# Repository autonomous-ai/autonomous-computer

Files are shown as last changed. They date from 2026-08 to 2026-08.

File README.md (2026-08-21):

# Time to build your own Personal AI Computer

https://github.com/user-attachments/assets/36f7aa02-42ac-4b35-b757-a5dd3b43ef1a

## Prefer a finished machine?

Building from this guide is the full DIY path. If you'd rather skip sourcing, CNC, and assembly, we have it covered — [order a Personal AI Computer](https://www.autonomous.ai/computer/buy).

## The future of AI is local

AI in 2026 looks like computing in 1975: the intelligence lives in a few mainframes, owned by a few companies, and you rent it by the token. Everyone knows how that movie ends. The machine moves onto the desk — and the people who own their machines build everything that comes next.

The Personal AI Computer is that machine. The models are good, the GPUs are affordable, and homes and businesses are reaching the same answer: bring it in-house. Three reasons:

1. **No one can switch you off.** In June 2026 the US government took Fable 5 offline for most of a month and gated GPT-5.6 behind an approved-partner list. Weights on your own disk can't be revoked.
2. **Your business is their training data.** Every prompt you send OpenAI or Anthropic carries your product, your process, your edge. They will turn your secret sauce into their product.
3. **Inference becomes free.** Open weights on a cloud API already cut the bill 20–30×. On your own machine there is no bill at all. No API, no meter.

## The end-to-end open-source local AI stack

Open software lets you run and shape your AI; open hardware lets you build, repair, and improve the machine it runs on. With both in your hands — the code, the CAD, the BOM, the BIOS settings — you can build the whole thing end to end. So we open-source both:

- **Open Source Hardware — this repo.** Your Personal AI Computer in five builds, below: every part, every bracket, every BIOS setting, every assembly photo.
- **Open Source Software — your choice.** The easiest way is [Grid](https://github.com/autonomous-ai/autonomous-grid), the open orchestrator for local AI — but any local AI engine works: vLLM, Ollama, llama.cpp.

## 2× NVIDIA RTX 5090

The entry-level build, for personal use. Enough for Llama, Qwen, and DeepSeek with quantization — run OpenClaw, Hermes Agent, or your own LangChain stack locally.

- **2× NVIDIA RTX 5090** — 64 GB VRAM · 3,584 GB/s · 419 FP32 TFLOPS
- **Intel Xeon W5** (ASUS W790 ACE) · 96 GB RAM · 1 TB NVMe
- **PCIe Gen 5 ×16** per GPU · 10 GbE + 2.5 GbE
- **1,550 W draw** · 1,600 W PSU
- **12.5″ × 12.5″ × 16″** · 33 lb

**[Build the 2× 5090 →](2x-5090/README.md)**

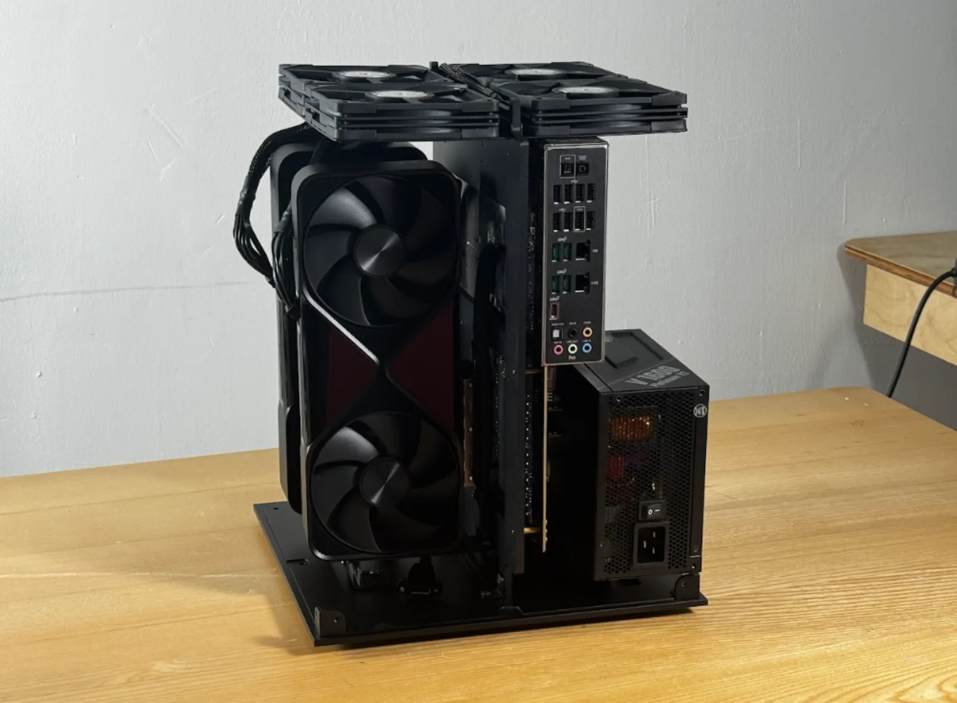
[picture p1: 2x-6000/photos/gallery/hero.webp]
The 2× 5090 build — two RTX 5090s on the open frame


<table>
<tr>
<td width="50%">Seating the PCIe riser</td>
<td width="50%">Mounting the PCIe 5.0 risers</td>
</tr>
<tr>
<td width="50%">The fan tray</td>
<td width="50%">Closing the side panel</td>
</tr>
</table>

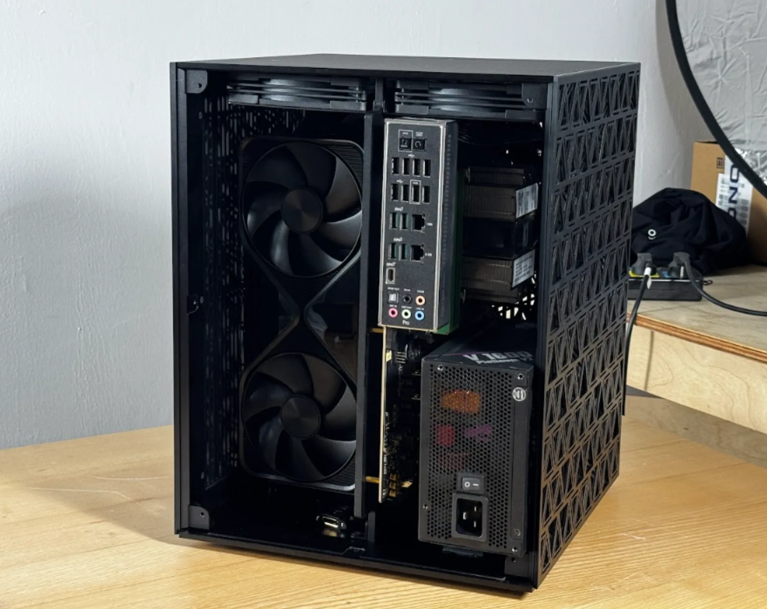
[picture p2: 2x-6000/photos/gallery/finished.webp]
The finished 2× 5090


## 2× NVIDIA RTX PRO 6000

The same desk-sized box, three times the VRAM. 192 GB of ECC memory on two cards — run the big open models as released instead of quantizing them down to fit.

- **2× NVIDIA RTX PRO 6000 Blackwell** — 192 GB GDDR7 ECC · 3,584 GB/s (96 GB per card)
- **Intel Xeon W5** (ASUS W790 ACE) · 96 GB RAM · 1 TB NVMe
- **PCIe Gen 5 ×16** per GPU · 10 GbE + 2.5 GbE
- **1,600 W draw** · 1,600 W PSU
- **12.5″ × 12.5″ × 16″** · 33 lb

**[Build the 2× 6000 →](2x-6000/README.md)**

<a href="2x-6000/README.md">The 2× 6000 build — two RTX PRO 6000s on the open frame with the fan tray on top</a>

<table>
<tr>
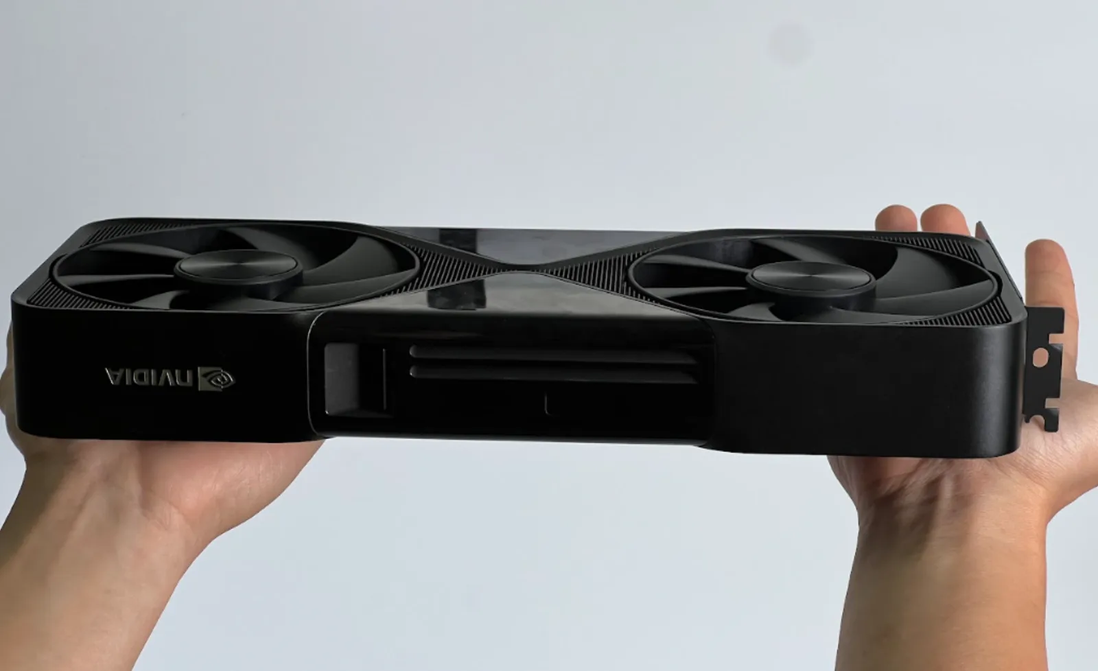
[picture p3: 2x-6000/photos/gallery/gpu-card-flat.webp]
The RTX PRO 6000 end-on
<td width="50%"></td>
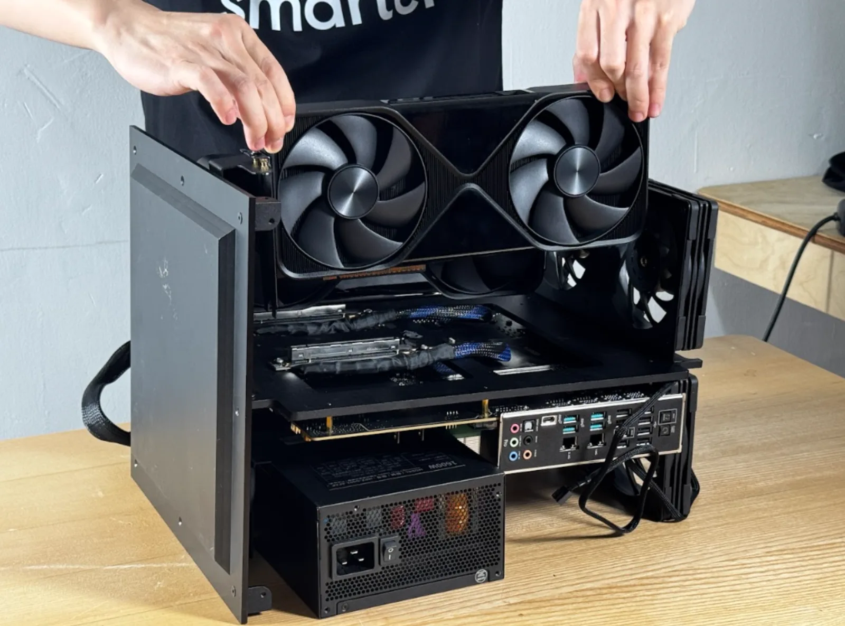
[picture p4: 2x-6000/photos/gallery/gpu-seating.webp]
Lowering the second card onto the riser
<td width="50%"></td>
</tr>
<tr>
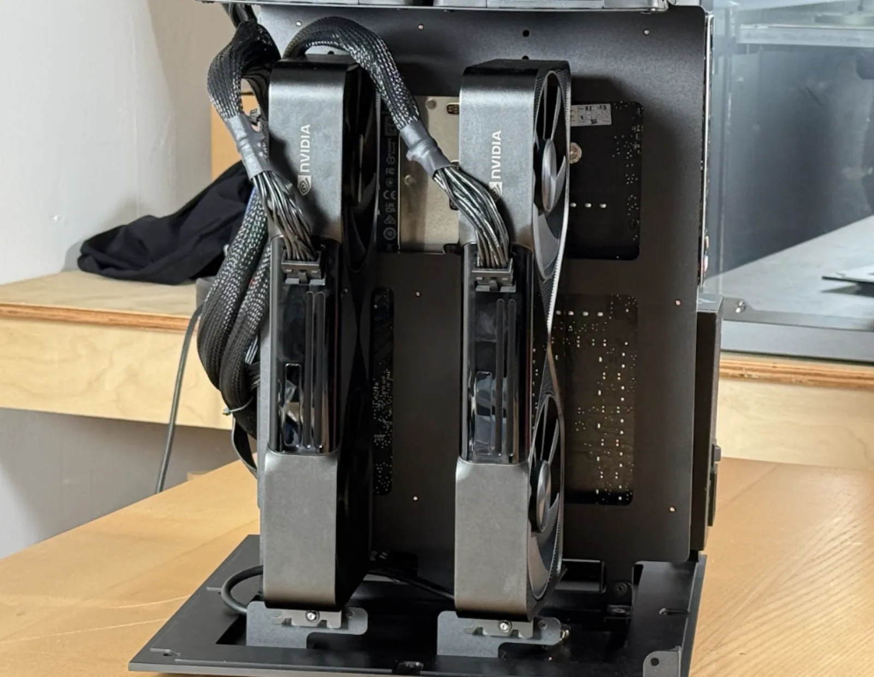
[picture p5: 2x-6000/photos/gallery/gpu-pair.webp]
Both cards mounted, 12VHPWR cables routed
<td width="50%"></td>
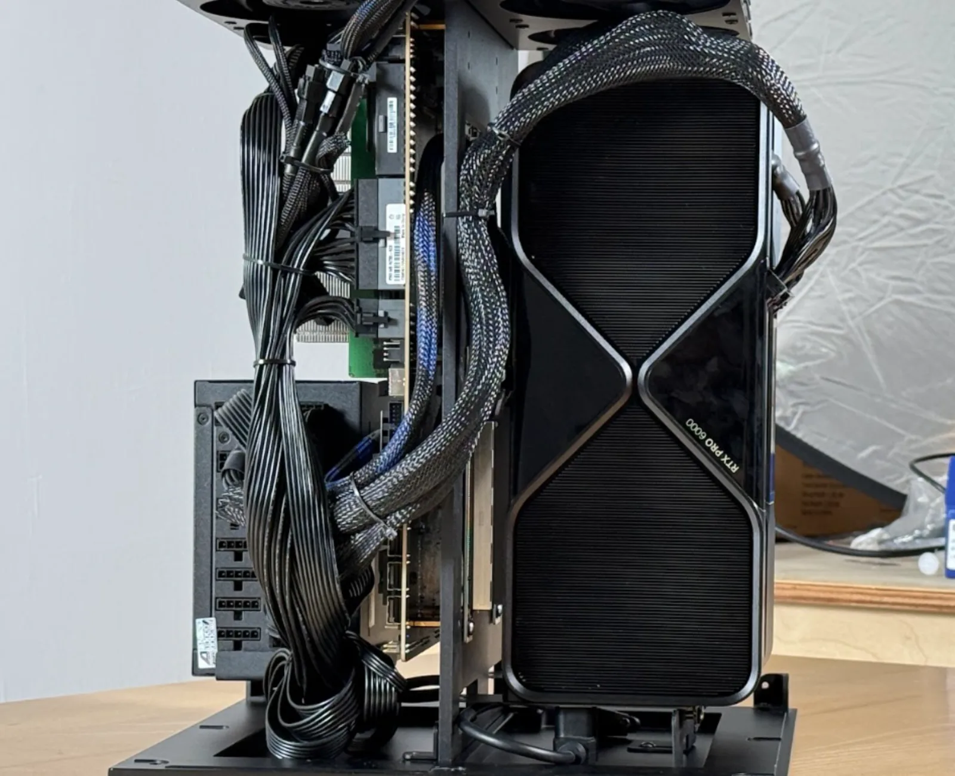
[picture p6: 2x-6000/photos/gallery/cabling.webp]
Cable routing down the side of the frame
<td width="50%"></td>
</tr>
</table>

The finished 2× 6000

## 4× NVIDIA RTX 5090

The team build. Larger open models like Kimi, MiniMax, and GLM. No API bills. Low latency. Private data.

- **4× NVIDIA RTX 5090** — 128 GB VRAM · 7,168 GB/s · 838 FP32 TFLOPS
- **AMD Ryzen Threadripper Pro** · 96 GB RAM · 1 TB NVMe
- **PCIe Gen 5 ×16** per GPU · 2× 10 GbE · BMC
- **2,750 W draw** · 4,000 W PSU
- **20″ × 20″ × 24″** · 66 lb

**[Build the 4× 5090 →](4x-5090/README.md)**

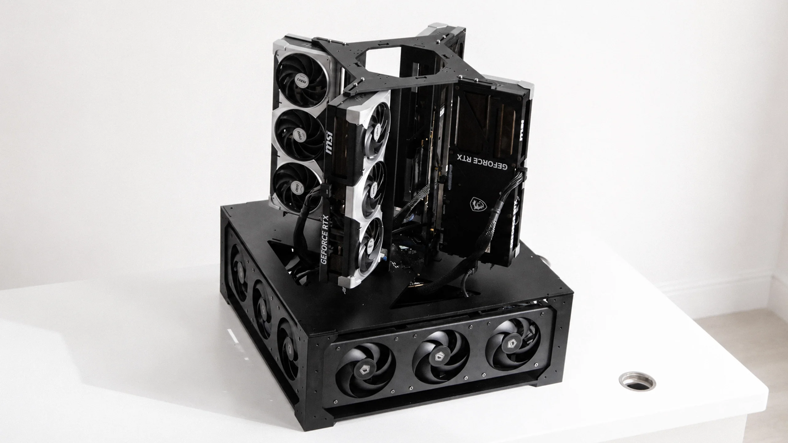
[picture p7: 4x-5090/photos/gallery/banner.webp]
The 4× 5090 build — four RTX 5090s stacked in the open cube frame over the fan base


<table>
<tr>
<td width="50%">Motherboard on the fan chassis</td>
<td width="50%">Cabling the power supplies</td>
</tr>
<tr>
<td width="50%">Mounting a GPU to the frame</td>
<td width="50%">All four RTX 5090s on the frame</td>
</tr>
</table>

The finished 4× 5090

## 4× NVIDIA RTX PRO 6000

The team build, in ECC. 384 GB of VRAM: fine-tune and serve the biggest open models as released, for a whole team.

- **4× NVIDIA RTX PRO 6000 Blackwell** — 384 GB GDDR7 ECC · 7,168 GB/s (96 GB per card)
- **Intel Xeon w5-3423** (ASUS Pro WS W790E-SAGE SE) · 192 GB DDR5 ECC · 2 TB NVMe
- **PCIe Gen 5 ×16** per GPU — 112 lanes across seven slots
- **4,000 W** — 2× 2,000 W, native 12V-2×6 · 240 V circuit
- **19.8″ × 19.8″ × 24.2″** · 66 lb

**[Build the 4× 6000 →](4x-6000/README.md)**

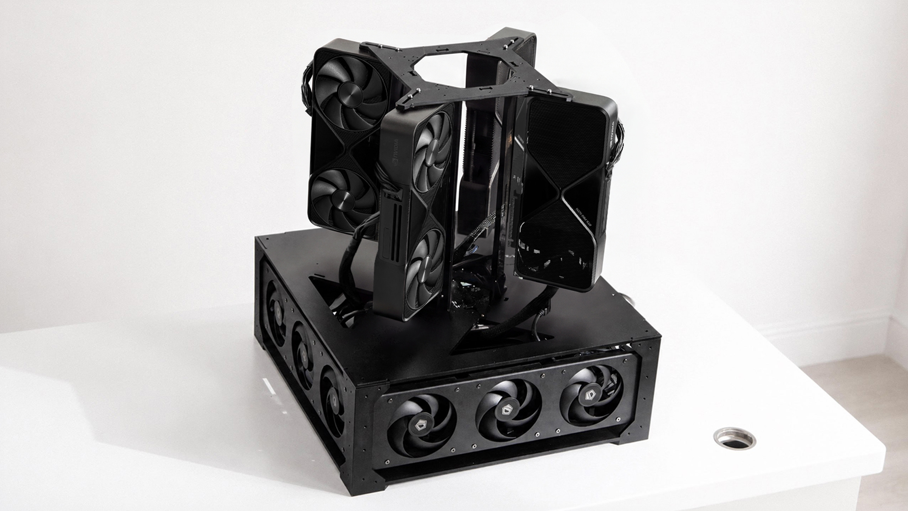
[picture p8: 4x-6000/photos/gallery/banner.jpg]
The 4× 6000 build — four RTX PRO 6000s stacked in the open cube frame over the fan base


<table>
<tr>
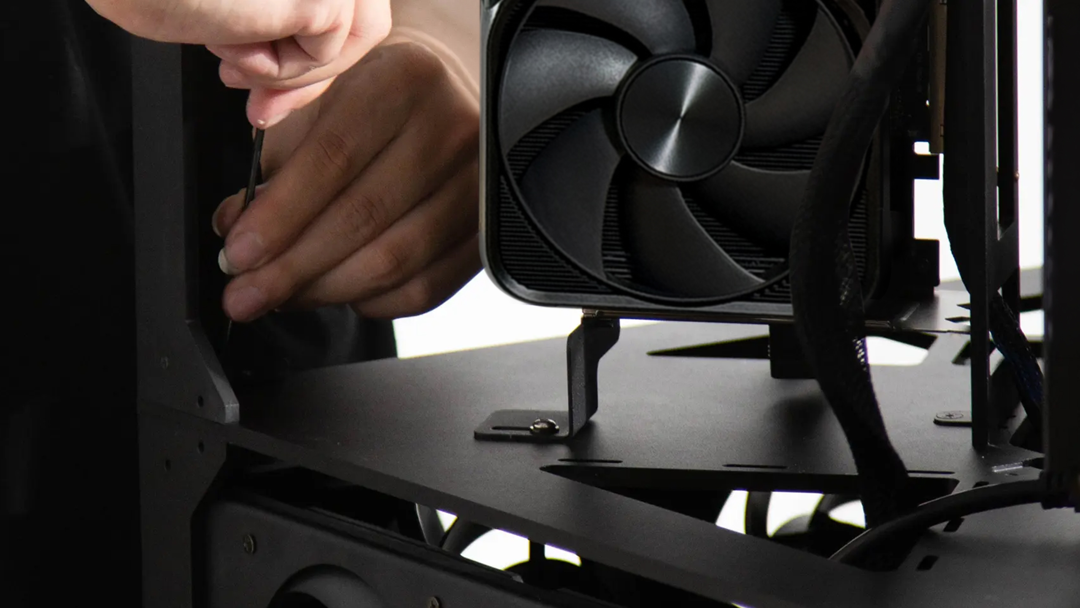
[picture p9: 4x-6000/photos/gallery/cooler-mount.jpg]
Mounting a GPU to the frame
<td width="50%"></td>
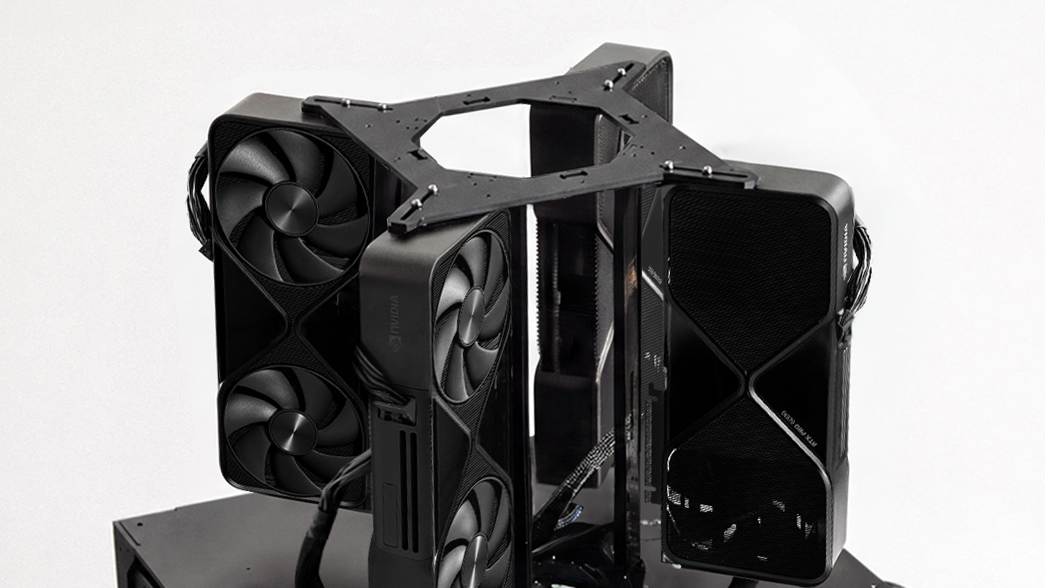
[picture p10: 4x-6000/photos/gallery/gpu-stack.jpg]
All four RTX PRO 6000s on the frame
<td width="50%"></td>
</tr>
<tr>
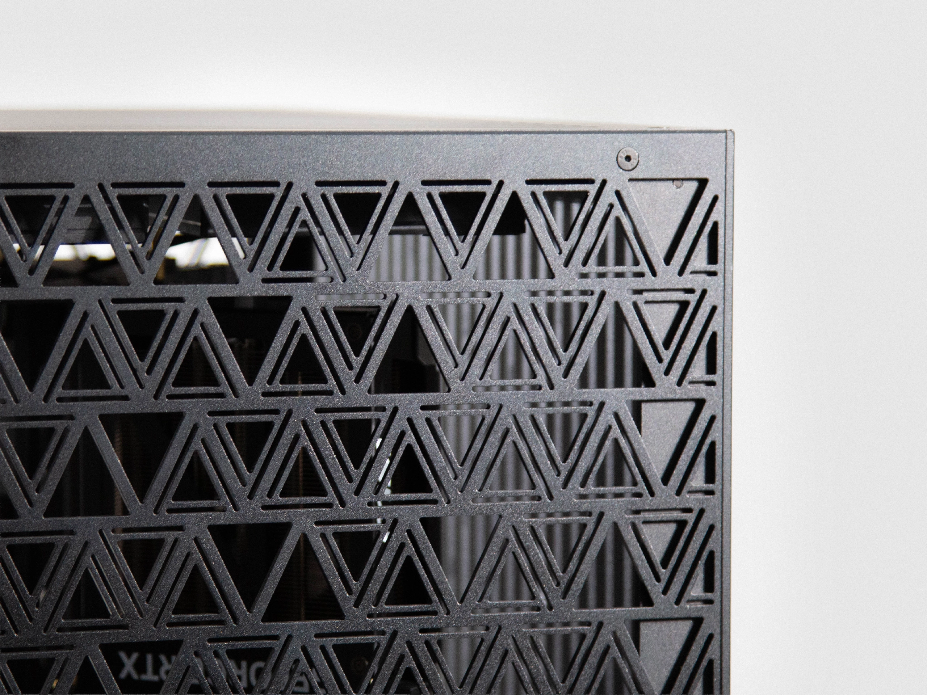
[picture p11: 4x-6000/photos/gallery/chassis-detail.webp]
The milled aluminium panel up close
<td width="50%"></td>
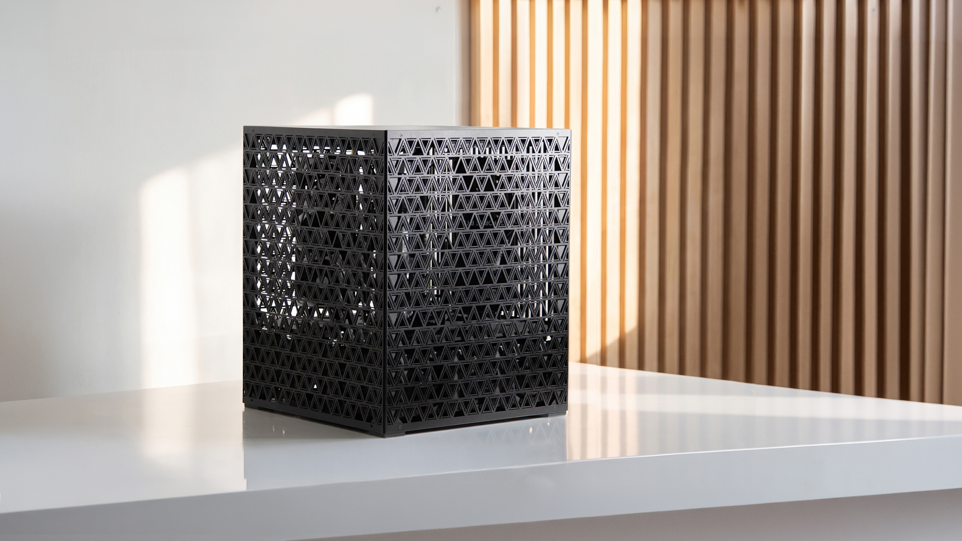
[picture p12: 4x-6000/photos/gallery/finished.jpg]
The finished 4× 6000 — panels on
<td width="50%"></td>
</tr>
</table>

## 8× NVIDIA RTX 5090

The on-prem build, for business. Develop, serve, and fine-tune with open models — the work that should never leave your floor.

- **8× NVIDIA RTX 5090** — 256 GB VRAM · 14,336 GB/s · 1,676 FP32 TFLOPS
- **2× AMD EPYC 9004** (ASRock Rack GENOA2D24G-2L+) · 192 GB RAM · 1 TB NVMe
- **PCIe Gen 5 ×16** per GPU, over MCIO · 2× 1 GbE · BMC
- **5,100 W draw** · 8,000 W PSU
- **5U rack chassis**

**[Build the 8× 5090 →](8x-5090/README.md)**

<a href="8x-5090/README.md">The finished 8× 5090 — 5U rack chassis, top cover off, both GPU columns and the center fan wall</a>

<table>
<tr>
<td width="50%">The dual-EPYC (Genoa) board — two SP5 sockets and twenty-four DIMM slots</td>
<td width="50%">Seating an RTX 5090 into the chassis</td>
</tr>
<tr>
<td width="50%">Top-down — the PCIe adapter boards, the center fan wall, and the MCIO cabling</td>
<td width="50%">The rear — 2,000 W CRPS power modules</td>
</tr>
</table>

## Software

1. **[BIOS tuning and GPU testing](setup.md)** — after you build the rig, run this to make sure it actually works: BIOS settings for multi-GPU, NVIDIA drivers, then confirm every GPU is detected, linked at full PCIe width, and stable under load.

gpu-testing

2. **Serve your models** — the rig runs, now put it to work. The easiest way is [Grid](https://github.com/autonomous-ai/autonomous-grid), the open orchestrator for local AI: it pools your machines into one local AI network. Or run any local AI engine — vLLM, Ollama, llama.cpp.

   ```bash
   curl -fsSL https://grid.autonomous.ai/install.sh | bash
   ```

home-grid (1)

## Contributing

Built one? Improved a part? Found a better component? See [**CONTRIBUTING.md**](CONTRIBUTING.md) — and [share your build](https://github.com/autonomous-ai/autonomous-computer/issues/new?template=share-your-build.md). The best community builds get featured.

## License

Open source under the [MIT License](LICENSE). Fork it, change it, build your own and sell it — we just want it built.

---

<div align="center">
<b>Autonomous</b> — the AI hardware company.<br>
Questions? <a href="https://github.com/autonomous-ai/autonomous-computer/issues">Open an issue.</a>
</div>

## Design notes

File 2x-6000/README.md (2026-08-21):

# 2× NVIDIA RTX PRO 6000

https://github.com/user-attachments/assets/f8960659-55fd-4ed9-966d-386108cae02e

The workstation build: two RTX PRO 6000 Blackwell GPUs on an Intel Xeon W platform, in the same desk-sized housing as the [2× 5090](../2x-5090/README.md). 192 GB of ECC VRAM — three times the 2× 5090 in the same box, enough to run the big open models unquantized without leaving your desk.

- **2× NVIDIA RTX PRO 6000 Blackwell** — 192 GB GDDR7 ECC · 3,584 GB/s (96 GB per card)
- **Intel Xeon W5** (ASUS W790 ACE) · 96 GB RAM · 1 TB NVMe
- **PCIe Gen 5 ×16** per GPU · 10 GbE + 2.5 GbE
- **1,600 W draw** · 1,600 W PSU
- **12.5″ × 12.5″ × 16″** · 33 lb

> **Draft guide** — same housing, board, and power as the 2× 5090; only the GPUs change. The step-by-step assembly photos are from the 2× 5090 build, since the 23 steps are identical; a testing screenshot from this build is landing soon.

## Prefer a finished machine?

Building from this guide is the full DIY path. If you'd rather skip sourcing, CNC, and assembly, we have it covered — [order the 2× 6000 built](https://www.autonomous.ai/computer-2).

## Build it

1. **Parts** — the [bill of materials](bom/bom.md), with a photo of every component. Lay them all out and check them off before you start.
2. **Housing** — the [STL files](../2x-5090/stl-models) and the [STEP files](../2x-5090/step_models). Identical to the 2× 5090 housing, so the files live there.
3. **Assemble** — the [photo-by-photo assembly guide](docs/assembly.md), 23 steps from bare housing to closed box.
4. **BIOS, drivers, testing** — the shared [BIOS tuning and GPU testing](../setup.md) guide. Board-specific notes below.
5. **Serve your models** — [Grid](https://github.com/autonomous-ai/autonomous-grid), the open orchestrator for local AI, or any local AI engine: vLLM, Ollama, llama.cpp.

<table>
<tr>
<td width="50%">The card end-on — two slots wide, blower-free triple-fan cooler</td>
<td width="50%">Lowering the second RTX PRO 6000 onto the riser</td>
</tr>
<tr>
<td width="50%">Both RTX PRO 6000s mounted, 12VHPWR cables routed</td>
<td width="50%">Cable routing down the side of the frame</td>
</tr>
</table>

## Why the PRO 6000 over the 5090

Same housing, same board, same wall outlet — the cards are the whole difference:

| | 2× RTX 5090 | 2× RTX PRO 6000 |
|:--|:--|:--|
| VRAM | 64 GB GDDR7 | **192 GB GDDR7 ECC** |
| Per card | 32 GB | 96 GB |
| Memory bandwidth | 3,584 GB/s | 3,584 GB/s |
| ECC | no | **yes** |

Three times the VRAM in the same box. That is the difference between quantizing a large model to make it fit and running it as released — and ECC memory means a long fine-tuning run doesn't silently corrupt.

## BIOS notes and testing

The two settings that matter on the W790 (the general list is in [the setup guide](../setup.md)):

```
Advanced -> PCI Subsystems Settings -> Enable Above 4G Decoding
Advanced -> PCI Subsystems Settings -> Enable Re-size BAR support
```

Board references: [motherboard manual](../2x-5090/docs/um-motherboard.pdf) · [BIOS manual](../2x-5090/docs/um-bios.pdf)

Then make sure both cards are detected, report full VRAM, and link at full PCIe width — the checklist is in [the setup guide](../setup.md#gpu-testing).

<!-- nvidia-smi screenshot from this build lands here. -->

## Serve your models

The rig runs, now put it to work. The easiest way is [Grid](https://github.com/autonomous-ai/autonomous-grid), the open orchestrator for local AI: it pools your machines into one local AI network. Or run any local AI engine — vLLM, Ollama, llama.cpp.

```bash
curl -fsSL https://grid.autonomous.ai/install.sh | bash
```

Grid — your machines pooled into one local AI network

## The finished machine

The finished 2× 6000 — panels on, ports and PSU at the back

<table>
<tr>
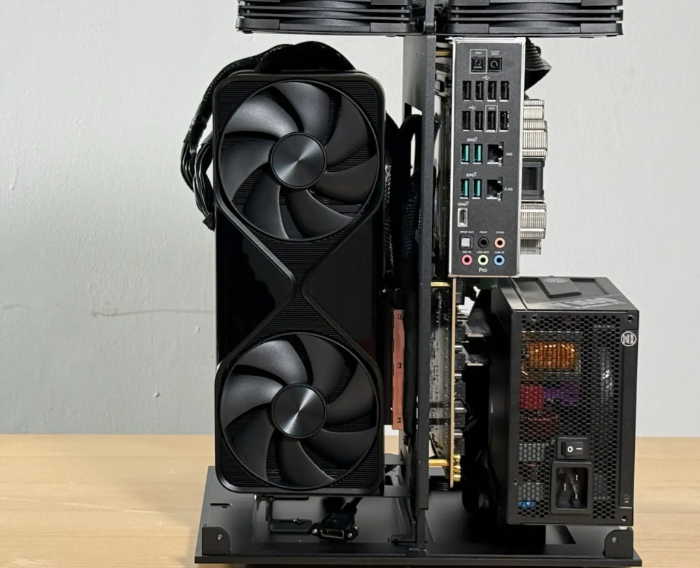
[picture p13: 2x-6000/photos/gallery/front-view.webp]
Front view — both cards behind the mesh
<td width="50%"></td>
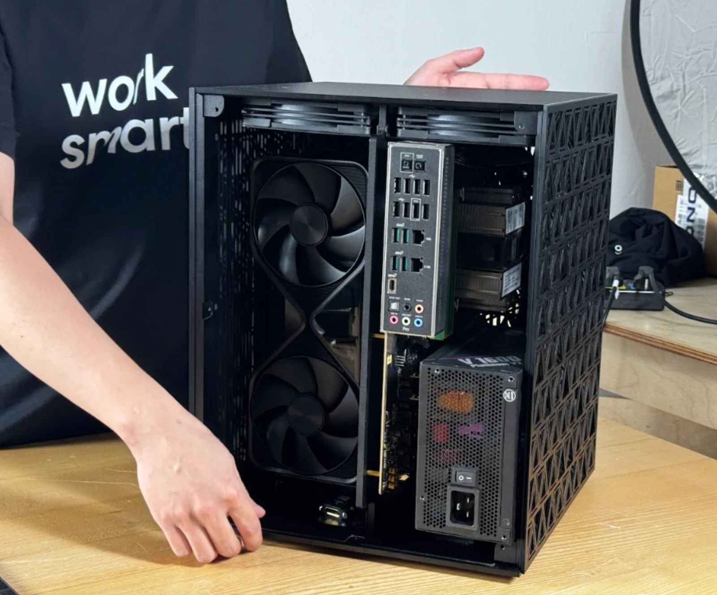
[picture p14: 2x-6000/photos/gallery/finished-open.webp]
Carrying the finished machine off the bench
<td width="50%"></td>
</tr>
</table>

## Other builds

The [2× 5090](../2x-5090/README.md) (the same box, 64 GB VRAM), the [4× 5090](../4x-5090/README.md) (the team build), the [4× 6000](../4x-6000/README.md) (384 GB VRAM), and the [8× 5090](../8x-5090/README.md) (on-prem scale) round out the family.

## License

Open source under the [MIT License](../LICENSE).

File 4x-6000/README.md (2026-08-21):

# 4× NVIDIA RTX PRO 6000

The 4× 6000 build — four RTX PRO 6000 Blackwell cards stacked in the open cube frame over the fan base

The team build, in ECC: four RTX PRO 6000 Blackwell GPUs in a cube housing milled from solid aluminium, on an Intel Xeon W platform. 384 GB of ECC VRAM — fine-tune and serve the biggest open models as released, for a whole team, on a machine that sits in the room with you.

- **4× NVIDIA RTX PRO 6000 Blackwell** — 384 GB GDDR7 ECC · 7,168 GB/s (96 GB per card)
- **Intel Xeon w5-3423** (ASUS Pro WS W790E-SAGE SE) · 192 GB DDR5 ECC · 2 TB NVMe
- **PCIe Gen 5 ×16** per GPU — 112 lanes across seven slots
- **4,000 W** — 2× 2,000 W, native 12V-2×6 · 240 V circuit
- **19.8″ × 19.8″ × 24.2″** · 66 lb

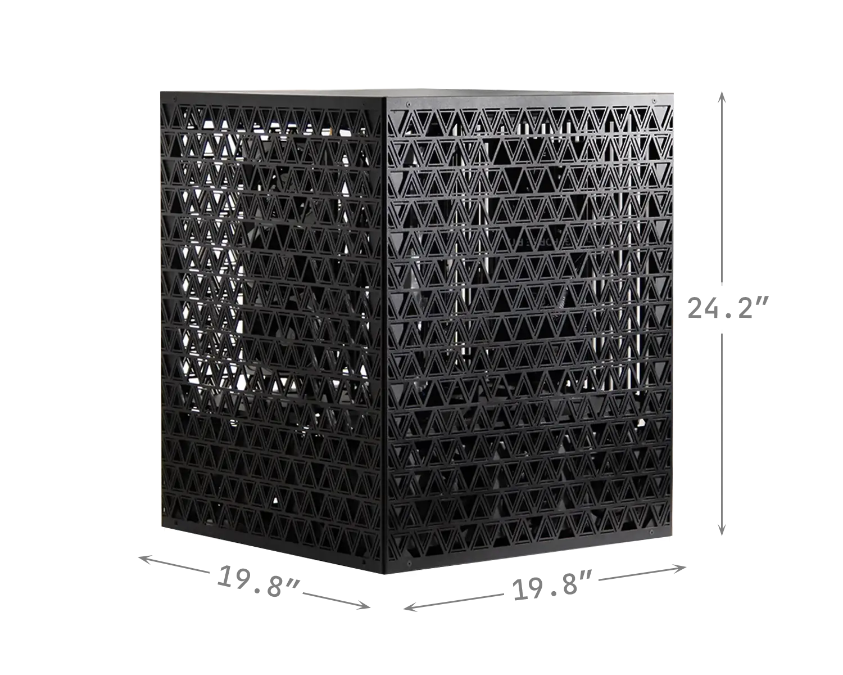
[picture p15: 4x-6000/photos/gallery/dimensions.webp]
The cube measured — 19.8″ wide, 19.8″ deep, 24.2″ tall


> **Draft guide** — the housing, board and power are confirmed; the step-by-step assembly photos, component photos, and a testing screenshot from this build are landing soon.

## Prefer a finished machine?

Building from this guide is the full DIY path. If you'd rather skip sourcing, CNC, and assembly, we have it covered — [order the 4× 6000 built](https://www.autonomous.ai/computer-4).

## Build it

1. **Parts** — the [bill of materials](bom/bom.md).
2. **Housing** — print the [STL files](../4x-5090/stl-models) or CNC the [STEP files](../4x-5090/step_models); the [housing prep](docs/prepare-me.md) is what to check before anything electronic goes near it.
3. **Lay out the electronics** — every part in the [bill of materials](bom/bom.md). Lay them all out and check them off before you start.
4. **Assemble** — the [step-by-step assembly guide](docs/assembly.md), 23 steps from bare housing to closed box.
5. **BIOS, drivers, testing** — the shared [BIOS tuning and GPU testing](../setup.md) guide. Board-specific notes below.
6. **Serve your models** — [Grid](https://github.com/autonomous-ai/autonomous-grid), the open orchestrator for local AI, or any local AI engine: vLLM, Ollama, llama.cpp.

<table>
<tr>
<td width="50%">Mounting a GPU to the frame</td>
<td width="50%">All four RTX PRO 6000s on the frame</td>
</tr>
</table>

## BIOS notes and testing

The 4× runs on an ASUS Pro WS W790E-SAGE SE. The settings that matter (the general list is in [the setup guide](../setup.md)):

```
Advanced -> PCI Subsystems Settings -> Enable Above 4G Decoding
Advanced -> PCI Subsystems Settings -> Enable Re-size BAR support
Set every GPU slot to PCIe Gen 5
```

The w5-3423's 112 PCIe 5.0 lanes are enough to give all four cards a full ×16 link, so nothing has to be bifurcated down — the thing to verify is that no slot has quietly negotiated ×8. For exact menu locations, see ASUS's Pro WS W790E-SAGE SE user guide.

Then make sure all four cards are detected, report full VRAM, and link at full PCIe width — the checklist is in [the setup guide](../setup.md#gpu-testing).

<!-- nvidia-smi screenshot from this build lands here. -->

## Serve your models

The rig runs, now put it to work. The easiest way is [Grid](https://github.com/autonomous-ai/autonomous-grid), the open orchestrator for local AI: it pools your machines into one local AI network. Or run any local AI engine — vLLM, Ollama, llama.cpp.

```bash
curl -fsSL https://grid.autonomous.ai/install.sh | bash
```

Grid — your machines pooled into one local AI network

## The finished machine

<table>
<tr>
<td width="50%">The finished 4× 6000 — panels on</td>
<td width="50%">The milled aluminium panel up close — the triangular mesh is the intake</td>
</tr>
</table>

## Discussion

Alternative platforms weighed on the way to this build — a dual-socket EPYC server variant, single-socket options, and a 3× H100 PCIe alternative — with verification notes: [brainstorm & discussion](docs/discussion.md).

## Other builds

The [2× 5090](../2x-5090/README.md) (start tonight), the [2× 6000](../2x-6000/README.md) (the same cards, desk-sized), the [4× 5090](../4x-5090/README.md) (the team build), and the [8× 5090](../8x-5090/README.md) (on-prem scale) scale the same idea down and up.

## License

Open source under the [MIT License](../LICENSE).

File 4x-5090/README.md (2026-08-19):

# 4× NVIDIA RTX 5090

The 4× 5090 build — four RTX 5090s stacked in the open cube frame over the fan base

The team build: four RTX 5090s in a cube housing on an AMD Ryzen Threadripper PRO platform. Built for larger open models like Kimi, MiniMax, and GLM. No API bills. Low latency. Private data.

- **4× NVIDIA RTX 5090** — 128 GB VRAM · 7,168 GB/s · 838 FP32 TFLOPS
- **AMD Ryzen Threadripper PRO** · 96 GB RAM · 1 TB NVMe
- **PCIe Gen 5 ×16** per GPU · 2× 10 GbE · BMC
- **2,750 W draw** · 4,000 W PSU
- **20″ × 20″ × 24″** · 66 lb

> **Draft guide** — component photos are representative and a few specs are still being confirmed; the real build photos, the board manual, and a testing screenshot are landing soon.

## Prefer a finished machine?

Building from this guide is the full DIY path. If you'd rather skip sourcing, CNC, and assembly, we have it covered — [order the 4× 5090 built](https://www.autonomous.ai/computer-4).

## Build it

1. **Parts** — the [bill of materials](bom/bom.md).
2. **Housing** — the [STL files](stl-models) and the [STEP files](step_models).
3. **Lay out the electronics** — the [component checklist](docs/prepare-ee.md), with a photo of every part.
4. **Assemble** — the [step-by-step assembly guide](docs/assembly.md), 23 steps from bare housing to closed box.
5. **BIOS, drivers, testing** — the shared [BIOS tuning and GPU testing](../setup.md) guide. Board-specific notes below.
6. **Serve your models** — [Grid](https://github.com/autonomous-ai/autonomous-grid), the open orchestrator for local AI, or any local AI engine: vLLM, Ollama, llama.cpp.

<table>
<tr>
<td width="50%">Motherboard on the fan chassis</td>
<td width="50%">Cabling the power supplies</td>
</tr>
<tr>
<td width="50%">Mounting a GPU to the frame</td>
<td width="50%">All four RTX 5090s on the frame</td>
</tr>
</table>

## BIOS notes and testing

The 4× runs on an AMD Ryzen Threadripper PRO (WRX90) board. The settings that matter (the general list is in [the setup guide](../setup.md)):

```
Enable Above 4G Decoding
Enable Re-size BAR support
Set every GPU slot to PCIe Gen 5 (with bifurcation as the board requires)
```

Exact menu paths depend on the motherboard — the board model and manual are being finalized.

Then make sure all four cards are detected, report full VRAM, and link at full PCIe width — the checklist is in [the setup guide](../setup.md#gpu-testing). A verification screenshot from this build is coming.

## Serve your models

The rig runs, now put it to work. The easiest way is [Grid](https://github.com/autonomous-ai/autonomous-grid), the open orchestrator for local AI: it pools your machines into one local AI network. Or run any local AI engine — vLLM, Ollama, llama.cpp.

```bash
curl -fsSL https://grid.autonomous.ai/install.sh | bash
```

Grid — your machines pooled into one local AI network

## The finished machine

The finished 4× 5090

## Other builds

The [2× 5090](../2x-5090/README.md) (start tonight), the [2× 6000](../2x-6000/README.md) (desk-sized, 192 GB VRAM), the [4× 6000](../4x-6000/README.md) (384 GB VRAM), and the [8× 5090](../8x-5090/README.md) (on-prem scale) round out the family.

## License

Open source under the [MIT License](../LICENSE).

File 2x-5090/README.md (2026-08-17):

# 2× NVIDIA RTX 5090

The 2× 5090 build — two RTX 5090s on the open frame

The entry-level Personal AI Computer: two RTX 5090s on an Intel Xeon W platform. Desk-sized, runs on a normal wall outlet, and enough VRAM for Llama, Qwen, and DeepSeek with quantization — run OpenClaw, Hermes Agent, or your own LangChain stack with zero API spend.

- **2× NVIDIA RTX 5090** — 64 GB VRAM · 3,584 GB/s · 419 FP32 TFLOPS
- **Intel Xeon W5** (ASUS W790 ACE) · 96 GB RAM · 1 TB NVMe
- **PCIe Gen 5 ×16** per GPU · 10 GbE + 2.5 GbE
- **1,550 W draw** · 1,600 W PSU
- **12.5″ × 12.5″ × 16″** · 33 lb

## Prefer a finished machine?

Building from this guide is the full DIY path. If you'd rather skip sourcing, CNC, and assembly, we have it covered — [order the 2× 5090 built](https://www.autonomous.ai/computer-2).

## Build it

1. **Parts** — the [bill of materials](bom/bom.md).
2. **Housing** — the [STL files](stl-models) and the [STEP files](step_models).
3. **Lay out the electronics** — the [component checklist](docs/prepare-ee.md), with a photo of every part.
4. **Assemble** — the [photo-by-photo assembly guide](docs/assembly.md), 23 steps from bare housing to closed box.
5. **BIOS, drivers, testing** — the shared [BIOS tuning and GPU testing](../setup.md) guide. Board-specific notes below.
6. **Serve your models** — [Grid](https://github.com/autonomous-ai/autonomous-grid), the open orchestrator for local AI, or any local AI engine: vLLM, Ollama, llama.cpp.

<table>
<tr>
<td width="50%">Seating the PCIe riser</td>
<td width="50%">Mounting the PCIe 5.0 risers</td>
</tr>
<tr>
<td width="50%">The fan tray</td>
<td width="50%">Closing the side panel</td>
</tr>
</table>

## BIOS notes and testing

The two settings that matter on the W790 (the general list is in [the setup guide](../setup.md)):

```
Advanced -> PCI Subsystems Settings -> Enable Above 4G Decoding
Advanced -> PCI Subsystems Settings -> Enable Re-size BAR support
```

Board references: [motherboard manual](docs/um-motherboard.pdf) · [BIOS manual](docs/um-bios.pdf)

Then make sure both cards are detected, report full VRAM, and link at full PCIe width — the checklist is in [the setup guide](../setup.md#gpu-testing).

<p align="center">
    nvidia-smi with both RTX 5090s detected
</p>

## Serve your models

The rig runs, now put it to work. The easiest way is [Grid](https://github.com/autonomous-ai/autonomous-grid), the open orchestrator for local AI: it pools your machines into one local AI network. Or run any local AI engine — vLLM, Ollama, llama.cpp.

```bash
curl -fsSL https://grid.autonomous.ai/install.sh | bash
```

Grid — your machines pooled into one local AI network

## The finished machine

The finished 2× 5090 on a desk

## Other builds

Need more? The [2× 6000](../2x-6000/README.md) (this exact box, 192 GB VRAM), the [4× 5090](../4x-5090/README.md) (the team build), the [4× 6000](../4x-6000/README.md) (384 GB VRAM), and the [8× 5090](../8x-5090/README.md) (on-prem scale) scale the same idea up.

## License

Open source under the [MIT License](../LICENSE).

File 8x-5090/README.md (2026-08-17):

# 8× NVIDIA RTX 5090

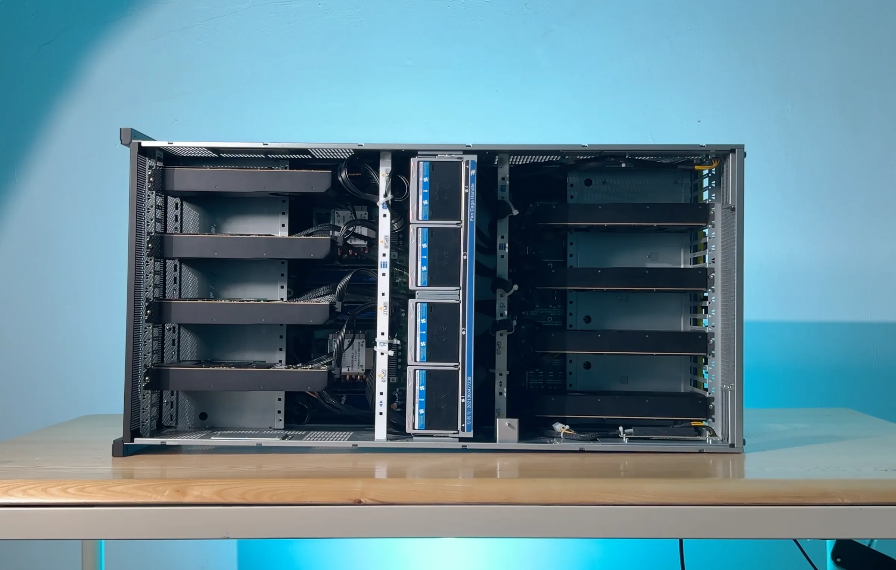
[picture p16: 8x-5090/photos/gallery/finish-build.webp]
The finished 8× 5090 — eight GPUs in the 5U rack chassis, top cover off


The on-prem build, for business: eight GPUs on a dual-EPYC (Genoa) platform in a 5U rack chassis. A team's AI on your own floor, where your IP and data never leave the building.

- **8× NVIDIA RTX 5090** — 256 GB VRAM · 14,336 GB/s · 1,676 FP32 TFLOPS
- **2× AMD EPYC 9004** (ASRock Rack GENOA2D24G-2L+) · 192 GB RAM · 1 TB NVMe
- **PCIe Gen 5 ×16** per GPU, over MCIO · 2× 1 GbE · BMC
- **5,100 W draw** · 8,000 W PSU
- **5U rack chassis**

## Prefer a finished machine?

Building from this guide is the full DIY path. If you'd rather skip sourcing, CNC, and assembly, we have it covered — [order the 8× 5090 built](https://www.autonomous.ai/computer-8).

## Build it

1. **Parts** — the [bill of materials](bom/bom.md).
2. **Housing** — the [5U chassis kit](docs/prepare-me.md) ships complete.
3. **Lay out the electronics** — the [component checklist](docs/prepare-ee.md), with a photo of every part.
4. **Assemble** — the [step-by-step assembly guide](docs/assembly.md), 13 steps from bare chassis to first boot.
5. **BIOS, drivers, testing** — the shared [BIOS tuning and GPU testing](../setup.md) guide. Board-specific notes below.
6. **Serve your models** — [Grid](https://github.com/autonomous-ai/autonomous-grid), the open orchestrator for local AI, or any local AI engine: vLLM, Ollama, llama.cpp.

<table>
<tr>
<td width="50%">The dual-EPYC (Genoa) board — two SP5 sockets and twenty-four DIMM slots</td>
<td width="50%">Seating an RTX 5090 into the chassis</td>
</tr>
<tr>
<td width="50%">Top-down — the PCIe adapter boards, the center fan wall, and the MCIO cabling</td>
<td width="50%">The rear — 2,000 W CRPS power modules</td>
</tr>
</table>

## Inside the machine

<table>
<tr>
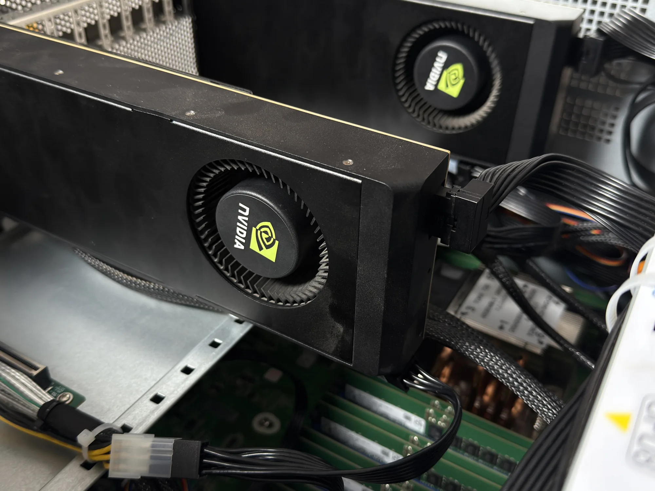
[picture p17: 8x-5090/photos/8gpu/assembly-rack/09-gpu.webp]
An RTX 5090 seated in the chassis, 12V-2x6 power connected
<td width="50%"></td>
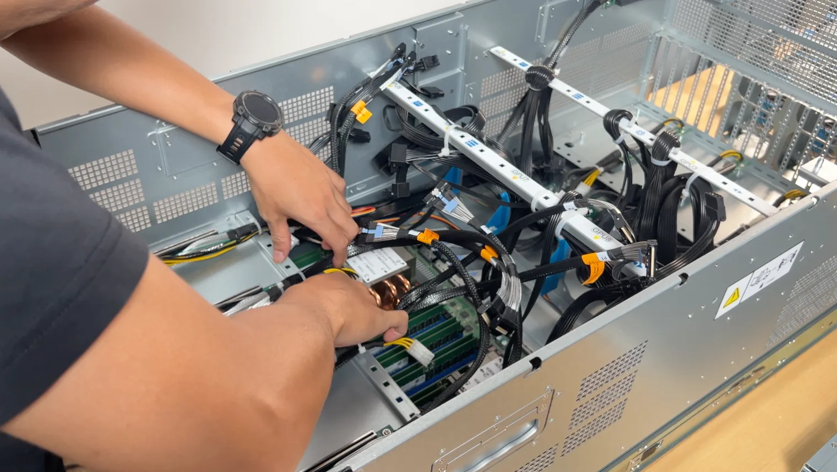
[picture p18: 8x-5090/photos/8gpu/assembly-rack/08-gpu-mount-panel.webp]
The numbered GPU rails and the MCIO and power cabling laid into the chassis
<td width="50%"></td>
</tr>
<tr>
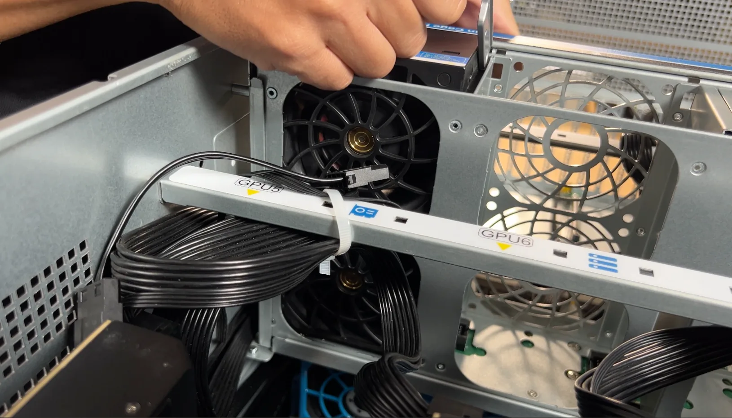
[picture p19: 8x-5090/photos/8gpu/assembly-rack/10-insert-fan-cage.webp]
A fan cage sliding into the center block, GPU5 and GPU6 rails alongside
<td width="50%"></td>
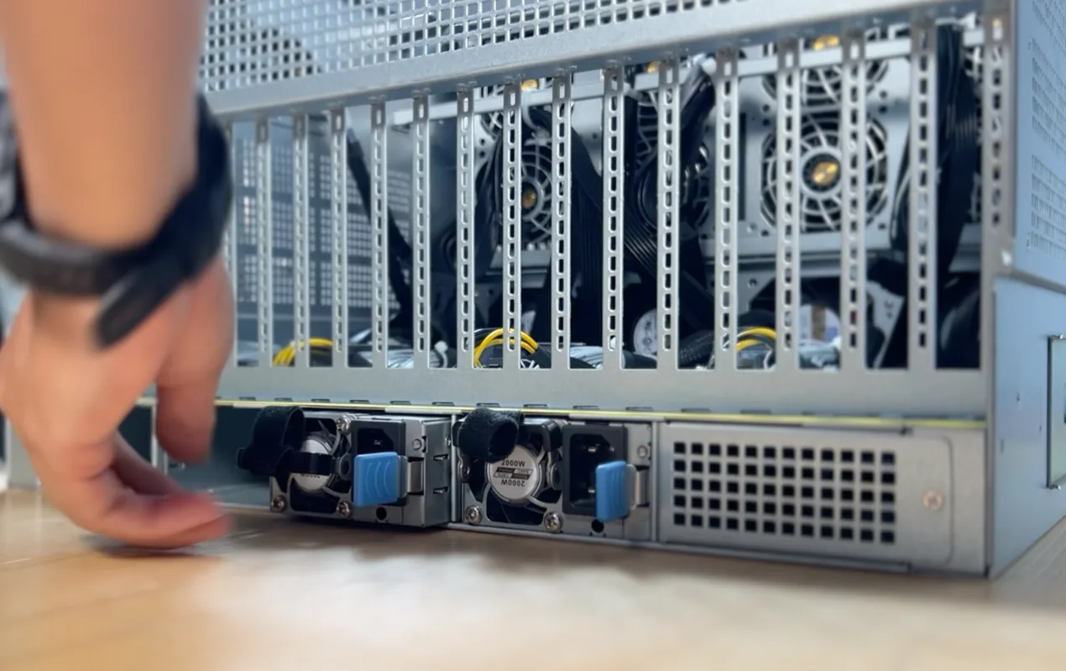
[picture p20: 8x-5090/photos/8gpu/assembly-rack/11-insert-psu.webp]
A 2,000 W CRPS module sliding into the rear power bay
<td width="50%"></td>
</tr>
</table>

https://github.com/user-attachments/assets/0b51e9fc-8865-4e1a-966e-9ce01fe8d8de

## BIOS notes and testing

The GENOA2D24G-2L+ feeds the GPUs over MCIO, so link width is the setting that matters most (the general list is in [the setup guide](../setup.md)):

```
Advanced -> Chipset Configuration -> PCIE link width
  -> set MCIO2/1, MCIO4/3, MCIO6/5, MCIO8/7, MCIO12/11, MCIO14/13, MCIO16/15, MCIO18/17 to x16
Advanced -> PCI Subsystems Settings -> Enable Re-size BAR support
```

Above 4G Decoding is typically enabled by default on this platform — verify it.

Board references: [motherboard manual](docs/um-motherboard.pdf) · [BMC manual](docs/um-bmc.pdf)

Then make sure all eight cards are detected, report full VRAM, and link at full PCIe width — the checklist is in [the setup guide](../setup.md#gpu-testing).

nvtop with all eight GPUs live

## Serve your models

The rig runs, now put it to work. The easiest way is [Grid](https://github.com/autonomous-ai/autonomous-grid), the open orchestrator for local AI: it pools your machines into one local AI network. Or run any local AI engine — vLLM, Ollama, llama.cpp.

```bash
curl -fsSL https://grid.autonomous.ai/install.sh | bash
```

Grid — your machines pooled into one local AI network

## The finished machine

The finished 8× 5090 — top cover off, both GPU columns and the center fan wall

## Other builds

Smaller footprint? The [2× 5090](../2x-5090/README.md) (start tonight), the [2× 6000](../2x-6000/README.md) (desk-sized, 192 GB VRAM), the [4× 5090](../4x-5090/README.md) (the team build), and the [4× 6000](../4x-6000/README.md) (384 GB VRAM) use the same playbook.

This build was previously housed in a CNC-milled desktop tower — those docs and CAD files are kept in [`archive/`](archive).

## License

Open source under the [MIT License](../LICENSE).

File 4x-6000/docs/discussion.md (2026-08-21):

# Brainstorm & Discussion — Alternative Build Options

Three alternative builds weighed while scoping the 4× RTX PRO 6000. All three were costed against a dual-socket EPYC 9124 server platform, which is the baseline they refer to below; the machine that shipped is the one in the [bill of materials](../bom/bom.md). Each table lists the proposed swap, the rationale, and a verification note.

---

## Option 1 — Higher-Speed Variant (RTX 5090)

| Component  | Proposed Swap | Rationale |
|:---|:---|:---|
| Mainboard  | ASRock Rack GENOAD12M-2Q (or equivalent single-socket) | Single-socket but keeps all 12 DIMM slots |
| CPU | AMD EPYC 9354 (32C) or 9454 (48C) | 2–3× the core count of 9124; higher clock to feed RTX 5090 without bottlenecking |
| RAM | 12× 64 GB DDR5-4800 / 5600 ECC RDIMM | Unchanged |
| GPU | RTX 5090 | Unchanged |
| SSD | Crucial T705 1 TB, or Samsung 990 Pro in RAID 0 | Move to PCIe 5.0 (T705) → ~14,500 MB/s read vs 7,450 MB/s on 990 Pro |
| PSU | 2000W Changcheng | Unchanged |

### Verification

| Claim | Verdict | Note |
|:---|:---:|:-----|
| `GENOAD12M-2Q` exists as ASRock Rack part number | ⚠️ | Single-socket SP5 boards from ASRock Rack exist (e.g. `GENOAD8X-2T`, `GENOAD8UD-2T/X550`). Verify the exact `GENOAD12M-2Q` SKU on ASRock Rack's site before ordering. |
| EPYC 9354 base clock (3.25 GHz) > 9124 (3.0 GHz) | ✅ | |
| EPYC 9454 has higher clock than 9124 | ❌ | 9454 base is **2.75 GHz**, *lower* than 9124. Core count is higher (48C), but the "higher clock" framing is wrong. |
| DDR5-5600 on EPYC 9004 (Genoa) | ⚠️ | Genoa is officially rated for **DDR5-4800** at 1 DPC. 5600 may run as overclock but is not guaranteed on EPYC server BIOS / QVL. |
| Crucial T705 ~14,500 MB/s vs 990 Pro ~7,450 MB/s | ✅ | Matches manufacturer specs. |

---

## Option 2 — Optimal (Single-Socket Turin + PCIe 5.0 RAID 0)

| Component  | Proposed Optimum | Why It's Faster & Cheaper |
|:---|:---|:---|
| CPU | AMD EPYC 9355 (Turin) | 32C/64T Zen 5; ~15–20% IPC uplift over Genoa; higher clock than 9354 → keeps RTX 5090 from bottlenecking |
| Mainboard  | Supermicro H13SSL-NT or Gigabyte ME03-CE0 | Dedicated single-socket SP5; Supermicro's stability is well known and pricing is friendlier than dual-socket boards |
| RAM | 12× 64 GB DDR5-6000 ECC RDIMM | **Key point:** Turin supports DDR5-6000 (vs 4800 on Genoa). Memory bandwidth improves by ~25%. |
| GPU | RTX 5090 | Unchanged |
| SSD | 2× Crucial T705 1 TB in RAID 0 | Two PCIe 5.0 drives in RAID 0 → ~28,000 MB/s sequential read. Feeds the 768 GB of RAM almost instantly. |
| Heatsink | Dynatron L31 or Noctua NH-D9 TR5-SP6 4U | Dynatron is server-grade and quieter than Coolserver; Noctua runs cooler and silent for focused work |
| PSU | FSP Cannon Pro 2000W Platinum | 80+ Platinum efficiency beats Changcheng → lower power bill and less waste heat |

### Verification

| Claim | Verdict | Note |
|:---|:---:|:-----|
| EPYC 9355 — 32C/64T Zen 5, base 3.55 GHz | ✅ | TDP 280 W. |
| Zen 5 IPC +15–20% vs Genoa | ✅ | AMD's published average is ~17% IPC. |
| 9355 clock (3.55 GHz) > 9354 (3.25 GHz) | ✅ | |
| Supermicro H13SSL-NT — single-socket SP5 | ✅ | Real product. |
| Gigabyte ME03-CE0 — single-socket SP5 | ✅ | Real product. |
| Turin supports DDR5-6000 (vs Genoa 4800), ~25% bandwidth uplift | ✅ | 6000/4800 = 1.25. |
| 2× T705 RAID 0 ~28,000 MB/s | ✅ (theoretical) | **No redundancy** — a single drive failure loses all data. Acceptable for scratch / dataset cache, not for OS / persistent state. |
| Noctua `NH-D9 TR5-SP6 4U` | ✅ | Real Noctua SKU for SP5/SP6 sockets (4U form factor). |
| Dynatron L31 for SP5 | ✅ | Real product. |
| FSP Cannon Pro 2000W Platinum | ✅ | Real; Platinum efficiency > typical Changcheng tier. |

---

## Option 3 — 3× H100 PCIe (LLM-First Build)

| Component  | Proposed Optimum | Reason |
|:---|:---|:---|
| CPU | AMD EPYC 9355 (Turin, 32C) | 2026-class build → Zen 5. Plenty of PCIe 5.0 lanes to feed 3× H100. |
| Mainboard  | Supermicro H13SSL-NT | PCIe slot spacing is wide enough for 3 thick cards |
| GPU | 3× NVIDIA H100 80GB (PCIe) | 240 GB HBM3 total. Fewer cards = fewer failure points and lower power draw than 8× RTX 5090. |
| RAM | 12× 64 GB DDR5-6000 ECC RDIMM | Keep the 768 GB RAM to stream data into the H100s |
| SSD | 2× Crucial T705 1 TB (RAID 0) | ~28 GB/s so data is never the bottleneck |
| PSU | FSP Cannon Pro 2000W Platinum | 3× H100 ≈ 1050 W + CPU/board ~400 W → 2000 W is very safe |
| Case | 4U / 7U Rackmount | H100 PCIe is **passively cooled** — needs a chassis with strong Delta/Sanyo front-to-back airflow. |

### Verification

| Claim | Verdict | Note |
|:---|:---:|:-----|
| H100 PCIe 80 GB, 350 W, HBM3, passive cooled | ✅ | |
| 3 × 80 GB = 240 GB total VRAM | ✅ | |
| Power: 3×350 + ~400 = 1450 W on a 2000 W PSU | ✅ | ~28% headroom — safe. |
| H100 PCIe requires chassis airflow (passive heatsink) | ✅ | Mandatory rackmount with high-static-pressure fans. |
| H13SSL-NT slot pitch fits 3 thick cards | ⚠️ | H13SSL-NT has 3× PCIe 5.0 x16 slots, but slot spacing isn't ideal for 3 dual-slot cards with long heatsinks. OK on paper for H100 PCIe's 2-slot passive shroud; confirm against datasheet slot pitch and chassis riser layout. |
| 4U is enough for 3× H100 + cooling | ⚠️ | 4U is tight. **5U+** or a dedicated GPU chassis is the safer envelope for sustained thermal load. |
| Fewer cards / lower power than 8× RTX 5090 | ✅ | 3×350 = 1050 W vs 8×575 = 4600 W. Also far higher memory bandwidth per dollar for LLM serving. |

---

## Summary

- **Option 1** is a moderate refresh — keep DDR5-4800, swap to a faster Genoa CPU and PCIe 5.0 SSD. Cheapest of the three. Verify the exact ASRock Rack SKU and don't claim higher clock for 9454.
- **Option 2** is the strongest single-node workstation: Turin gives both clock and a real ~25% memory bandwidth jump, RAID 0 PCIe 5.0 hits ~28 GB/s, and Platinum PSU pays itself back over time. Watch the RAID 0 redundancy story and double-check the Noctua part number.
- **Option 3** is the LLM-serving build: 3× H100 PCIe gives 240 GB of HBM3 with far better memory bandwidth than any consumer GPU stack. Plan chassis airflow carefully; 5U is the safer floor.

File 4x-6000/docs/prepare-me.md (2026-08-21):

# Preparation — Mechanical & Housing

The cube arrives as a flat set of milled parts — base, fan plate, two sides, top, corner and GPU mounts, and the outer mesh panels. Print them from the [STLs](../../4x-5090/stl-models) or have them CNC'd from the [STEPs](../../4x-5090/step_models) in solid aluminium, then check the set over before anything electronic goes near it.

| No  | Step | Notes |
|:---:|:---|:---|
|  1  | Lay out the housing set  | Base, fan plate, sides, top, corner mounts, GPU mounts, mesh panels |
|  2  | Inspect the milled faces | No burrs in the mesh; mating edges flat and square |
|  3  | Dry-fit the frame | Base to sides to top, no fasteners yet — confirm every hole lines up |
|  4  | Count the fittings | Brass hex standoffs, panel screws, fan screws, GPU mount screws |
|  5  | Stage the housing | Base on an anti-static workbench; panels set aside until the last step |

Next: [assembly](assembly.md).

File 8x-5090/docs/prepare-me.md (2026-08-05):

# Preparation — Mechanical & Housing

The 5U rack chassis kit (case, internal cables, fan blocks, and power board) is supplied as a complete unit, so no separate CNC / sheet-metal preparation is required for this build.

| No  | Step | Notes |
|:---:|:---|:---|
|  1  | Unbox 5U chassis  | Verify case, cable harness, fan blocks, power board |
|  2  | Inspect fittings  | Standoffs, screws, GPU support rail, rack ears |
|  3  | Stage chassis | Place on anti-static workbench |

Next: [assembly](assembly.md).

---

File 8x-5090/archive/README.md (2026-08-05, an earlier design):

# Archive — CNC desktop case

The 8× 5090 was originally built into a CNC-milled, anodized aluminum desktop tower — 15.5″ × 15.5″ × 24″, 110 lb. That build has been superseded by the **5U rack chassis**; see the [current build guide](../README.md).

Everything for the old housing is kept here for reference. None of it is part of the current build.

| | |
|:--|:--|
| [`assembly.md`](assembly.md) | The original 39-step assembly, bare plates to running machine |
| [`prepare-me.md`](prepare-me.md) | CNC milling → sand blasting → anodizing |
| [`step_models/`](step_models) | 15 STEP parts for CNC machining, plus the full assembled model |
| [`stl-models/`](stl-models) | 10 printable STL versions of the same parts |
| [`photos/assembly/`](photos/assembly) | Step photos for the 39-step build |
| [`photos/housing/`](photos/housing) | The housing being milled, blasted, and anodized |
| [`photos/renders/`](photos/renders) | Product renders of the desktop tower |

The electronics are unchanged between the two builds — the [bill of materials](../bom/bom.md) and [component checklist](../docs/prepare-ee.md) still apply, apart from the housing line.

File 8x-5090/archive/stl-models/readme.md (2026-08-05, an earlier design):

> **Archived.** These parts are for the original CNC-milled desktop housing. The 8× 5090 build now ships in a **5U rack chassis** — see the [current housing prep](../../docs/prepare-me.md). Kept here for reference; see the [archive index](../README.md).

Printable STL files for the 8× housing. CNC-ready STEP versions of the same parts are in [`../step_models`](../step_models).

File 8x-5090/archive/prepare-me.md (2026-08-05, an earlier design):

# Preparation — Mechanical & Housing (archived)

> **Archived.** This is the original CNC-milled desktop housing. The 8× 5090 now ships in a 5U rack chassis — see the [current housing prep](../docs/prepare-me.md).

The housing is CNC-milled aluminum from the [STEP files](step_models), then sand-blasted and anodized.

<table>
    <tr>
        <td valign="top" align="center" width="50%">
            <b>1. CNC milling</b><br>
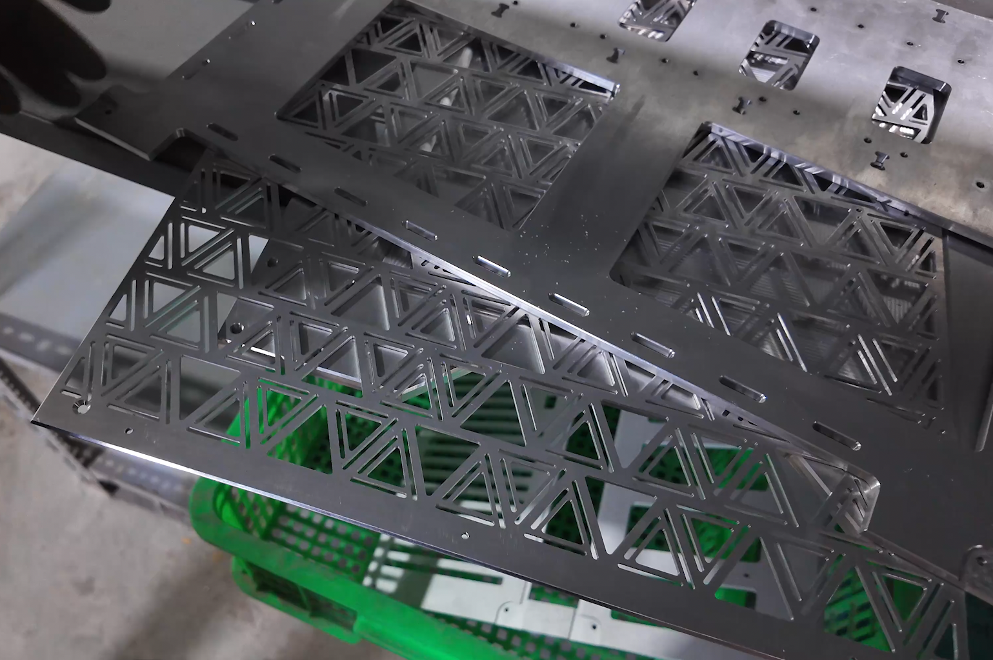
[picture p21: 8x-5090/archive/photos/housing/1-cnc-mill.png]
            <br>
            <b>3. Anodizing</b><br>
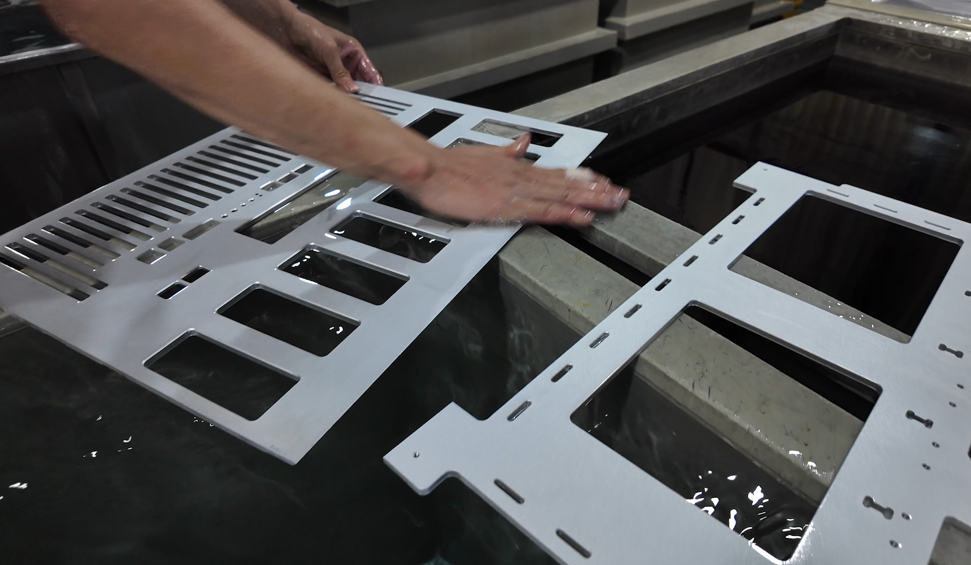
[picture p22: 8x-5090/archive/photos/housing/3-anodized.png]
            <br>
        </td>
        <td valign="top" align="center" width="50%">
            <b>2. Sand blasting</b><br>
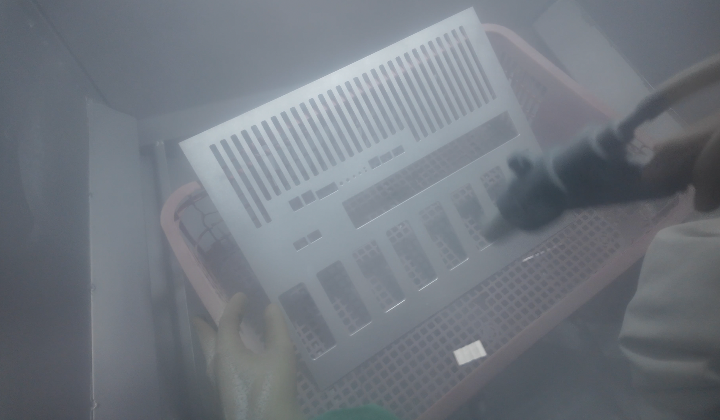
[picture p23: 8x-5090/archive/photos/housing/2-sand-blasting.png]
            <br>
            <b>4. Anodized parts</b><br>
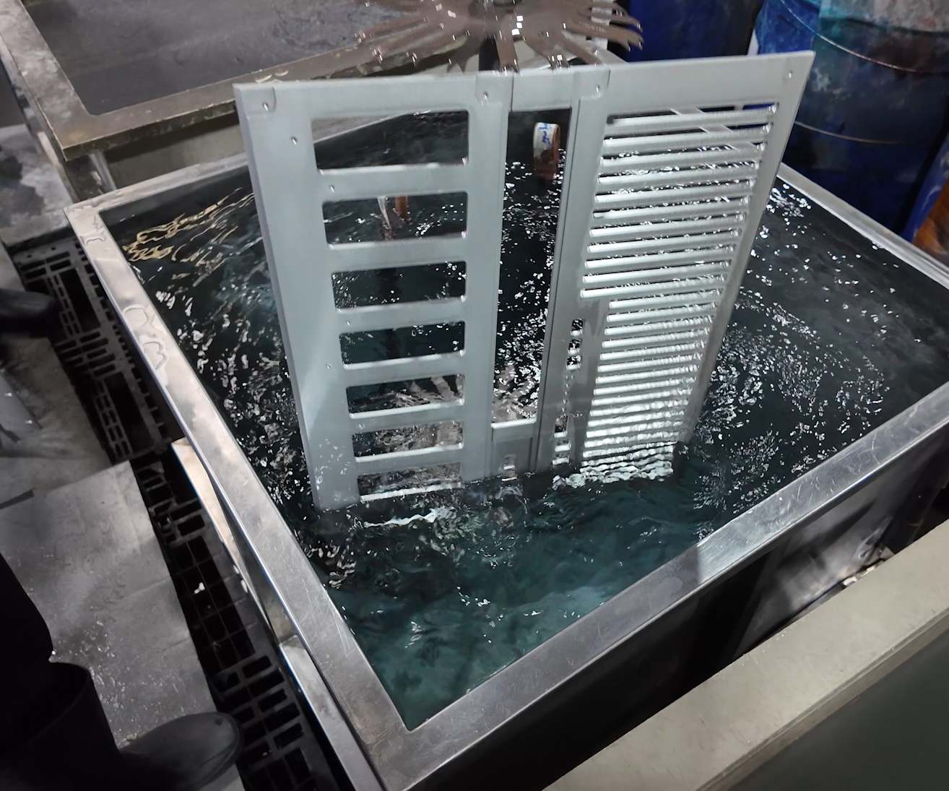
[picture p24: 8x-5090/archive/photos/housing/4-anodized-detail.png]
            <br>
        </td>
    </tr>
</table>

<p align="center">
    <video src="https://github.com/user-attachments/assets/05ee937c-a871-4809-914b-d98930b31777"></video>
</p>

Next: [assembly](assembly.md).

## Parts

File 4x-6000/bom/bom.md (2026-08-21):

# Bill of Materials

Quantities are per machine — one 4× RTX PRO 6000 build. Lay every part out and check it off before assembly.

> Draft — component photos from this build are landing soon.

| No  | Item | Detail | Qty | Category | Notes |
|:---:|:---|:---|:---:|:---|:---|
|  1  | Mainboard | ASUS Pro WS W790E-SAGE SE |  1  | Mainboard  | Intel W790, LGA 4677; 7× PCIe 5.0 ×16 |
|  2  | CPU | Intel Xeon w5-3423 |  1  | Processor  | 12 cores, LGA 4677, 112 PCIe 5.0 lanes |
|  3  | CPU heatsink | Heatsink 4677-2UAF8 |  1  | Cooling | LGA 4677 |
|  4  | RAM | 32 GB DDR5-4800 ECC |  6  | Memory | 192 GB total; configurable 64–256 GB |
|  5  | SSD | 2 TB NVMe PCIe 4.0 |  1  | Storage | Configurable 1–8 TB; Gen 5 at 8 TB |
|  6  | GPU | NVIDIA RTX PRO 6000 Blackwell Workstation Edition |  4  | Graphics | 96 GB GDDR7 ECC each — 384 GB total |
|  7  | PCIe 5.0 riser | PCIe 5.0 x16 riser cable |  4  | Cable | One per GPU |
|  8  | PSU | 2,000 W, native 12V-2x6 |  2  | Power | 4,000 W total; 240 V circuit required |
|  9  | GPU power cable | 12V-2x6 / 12VHPWR, 600 W rated |  4  | Cable | One per GPU |
| 10  | Power cord | Wall cord rated for the PSU |  2  | Cable | One per supply |
| 11  | Fan | 120 mm case fan | 18  | Cooling | Single controller |
| 12  | Frame housing | Full housing set (printed or CNC) |  1  | Housing | CNC-machined solid aluminium; print the [STLs](../../4x-5090/stl-models) or CNC the [STEPs](../../4x-5090/step_models) |

Next: [housing prep](../docs/prepare-me.md) · [assembly](../docs/assembly.md).

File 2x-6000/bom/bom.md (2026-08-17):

# Bill of Materials

Quantities are per machine — one 2× RTX PRO 6000 build. Lay every part out and check it off before assembly. Click a thumbnail to enlarge.

> This build shares the 2× 5090 platform and housing; only item 6 (the GPUs) differs. The GPU is photographed from this build.

| No  | Item | Image | Detail | Qty | Category | Notes |
|:---:|:---|:-----:|:---|:---:|:---|:---|
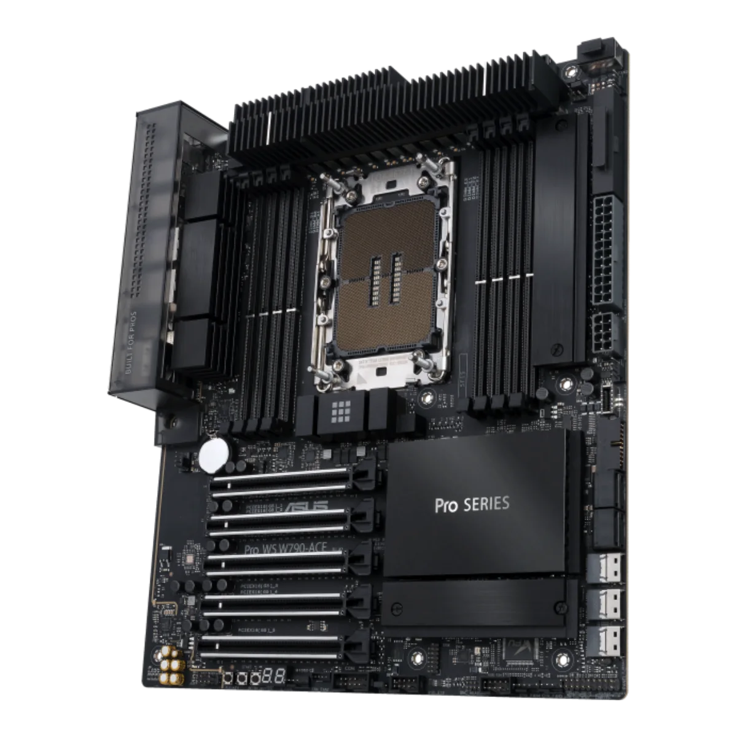
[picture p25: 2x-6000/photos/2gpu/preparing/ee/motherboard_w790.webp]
|  1  | Mainboard |  | ASUS W790 ACE |  1  | Mainboard  | Intel W790 chipset, LGA 4677 |
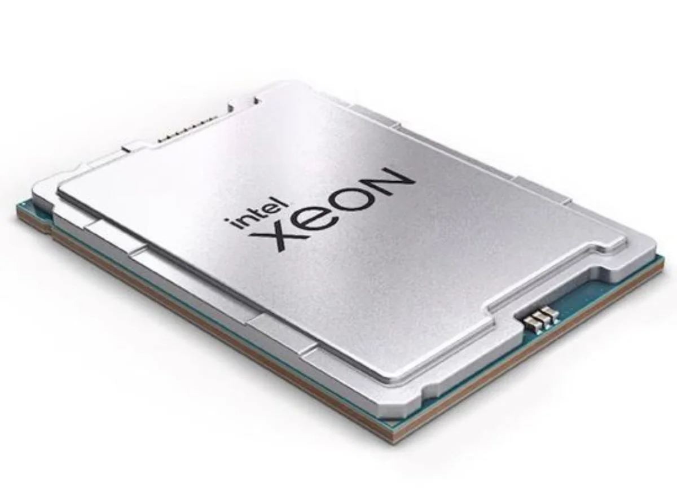
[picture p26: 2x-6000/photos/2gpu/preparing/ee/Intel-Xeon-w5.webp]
|  2  | CPU |  | Intel Xeon W5 |  1  | Processor  | LGA 4677 socket |
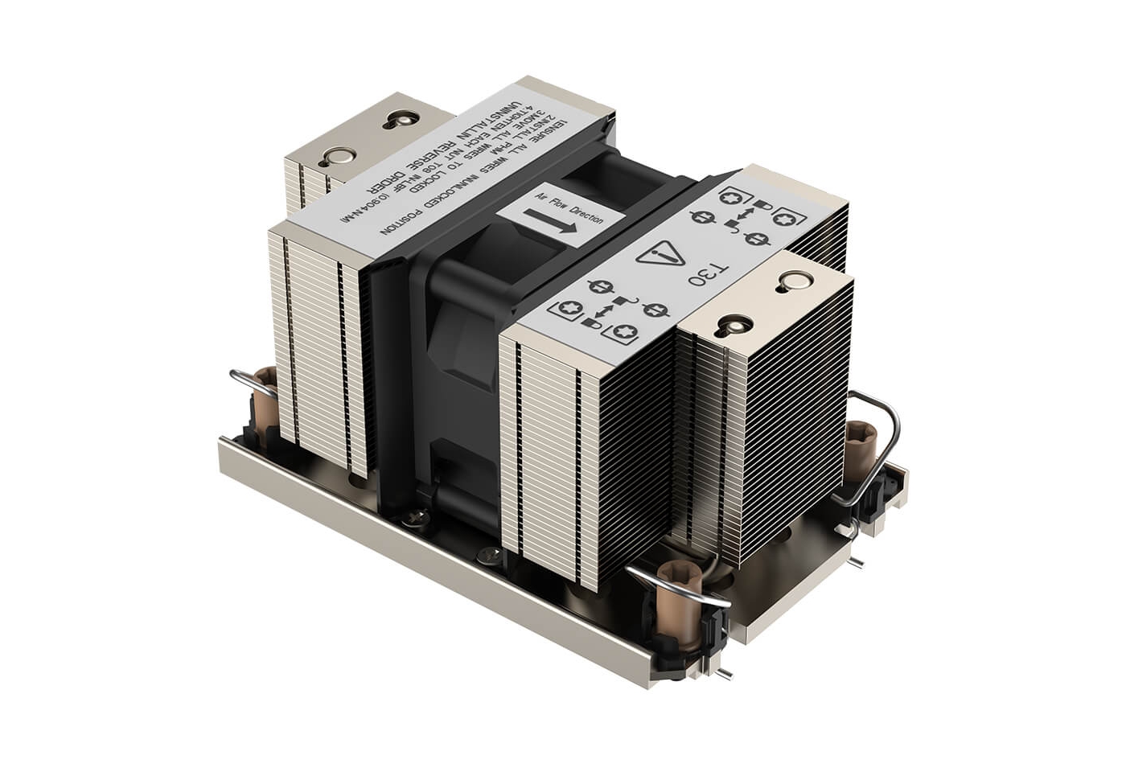
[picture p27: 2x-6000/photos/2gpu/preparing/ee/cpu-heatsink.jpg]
|  3  | CPU heatsink |  | LGA 4677-compatible cooler |  1  | Cooling | |
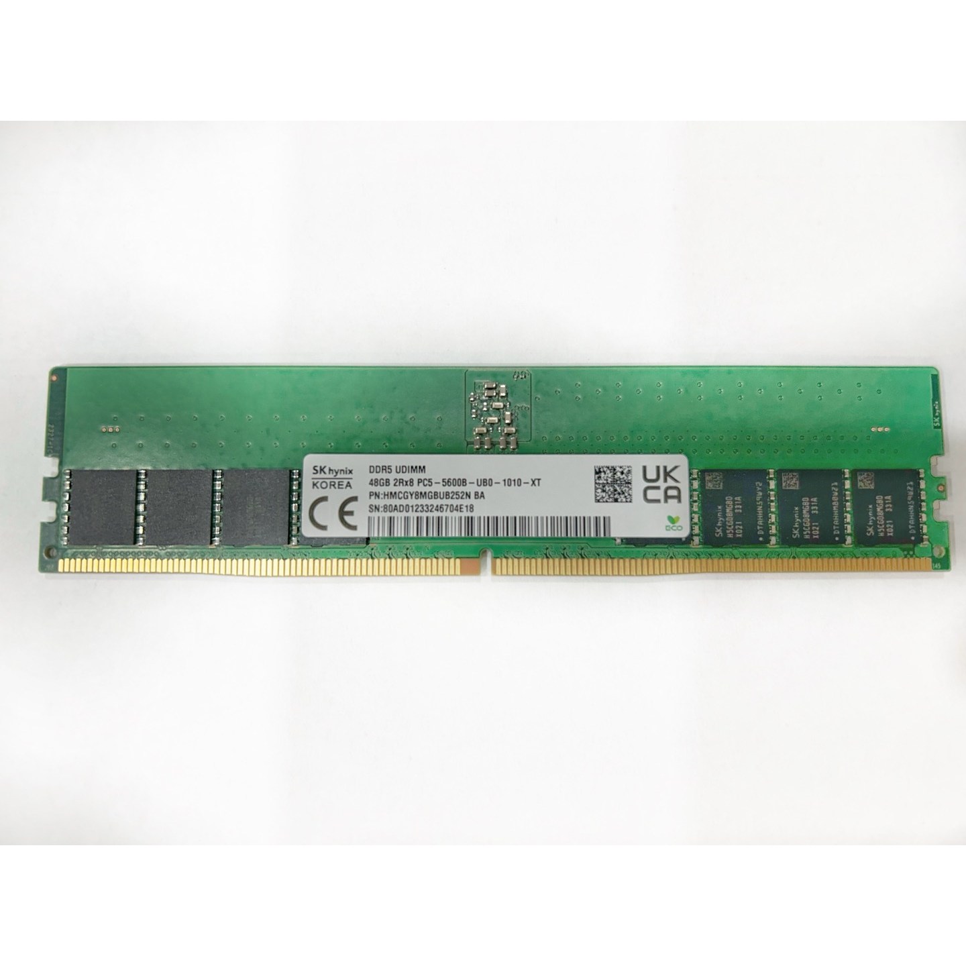
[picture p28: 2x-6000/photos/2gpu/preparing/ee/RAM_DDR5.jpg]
|  4  | RAM |  | DDR5 48 GB |  4  | Memory | 192 GB total; configurable 1–8 DIMMs |
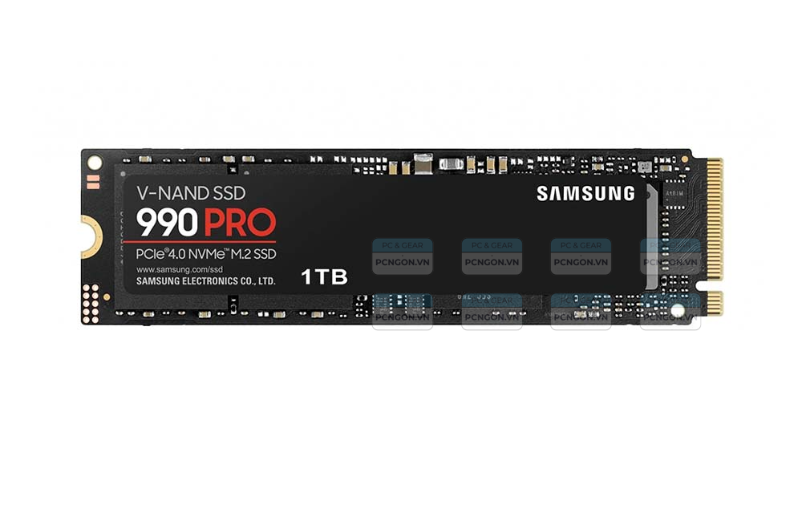
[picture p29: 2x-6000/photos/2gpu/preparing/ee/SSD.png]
|  5  | SSD |  | 1 TB NVMe |  1  | Storage | Capacity configurable |
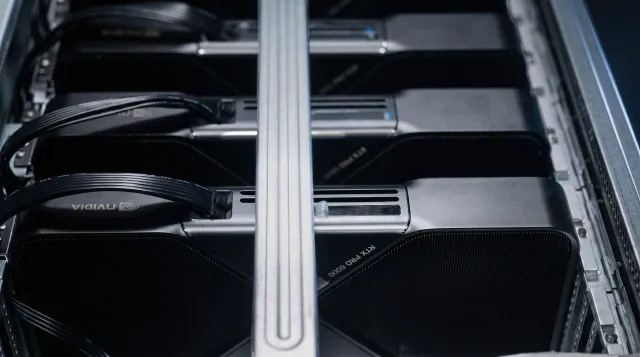
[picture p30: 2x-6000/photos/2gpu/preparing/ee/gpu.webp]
|  6  | GPU |  | NVIDIA RTX PRO 6000 Blackwell Workstation Edition |  2  | Graphics | 96 GB GDDR7 ECC each — 192 GB total |
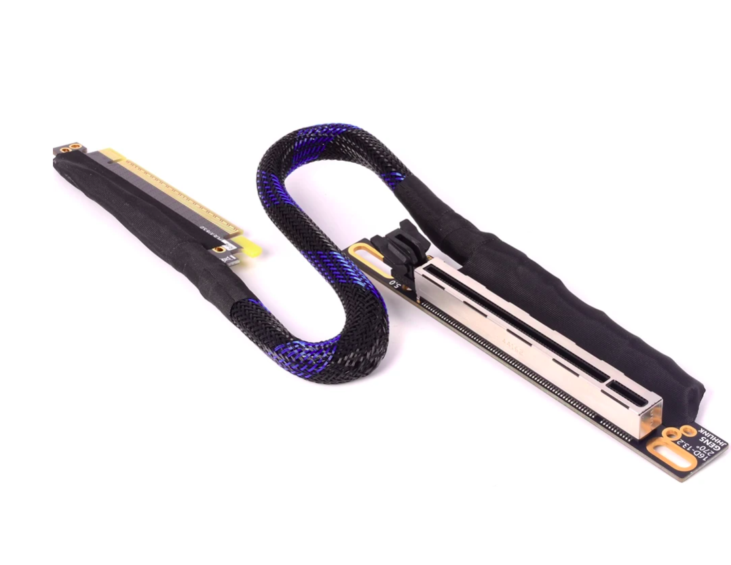
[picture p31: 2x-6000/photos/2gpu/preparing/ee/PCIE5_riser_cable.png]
|  7  | PCIe 5.0 riser |  | PCIe 5.0 x16 riser cable |  2  | Cable | One per GPU |
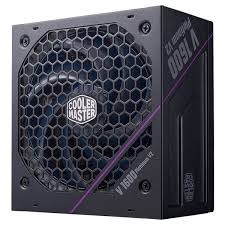
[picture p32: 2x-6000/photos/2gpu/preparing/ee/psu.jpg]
|  8  | PSU |  | 1600 W |  1  | Power | 600 W per card — confirm headroom on your wall circuit |
|  9  | GPU power cable |  | 12V-2x6 / 12VHPWR, 600 W rated |  2  | Cable | One per GPU |
| 10  | Power cord |  | Wall cord rated for the PSU |  1  | Cable | |
| 11  | Fan |  | Case fan |  4  | Cooling | |
| 12  | Frame housing | | Full housing set |  1  | Housing | Same as the 2× 5090 — print the [STLs](../../2x-5090/stl-models) or CNC the [STEPs](../../2x-5090/step_models) |

Next: [assembly](../docs/assembly.md).

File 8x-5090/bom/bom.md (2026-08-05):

# Bill of Materials

Quantities are per machine — one 8× GPU build. Part photos are in the [component checklist](../docs/prepare-ee.md).

| No  | Item | Detail | Qty | Category | Notes |
|:---:|:---|:---|:---:|:---|:---|
|  1  | Mainboard | ASRock Rack GENOA2D24G-2L+ |  1  | Mainboard  | Dual SP5, PCIe over MCIO |
|  2  | CPU | AMD EPYC 9004 series (Genoa) |  2  | Processor  | SP5 socket |
|  3  | CPU heatsink | SP5-compatible cooler |  2  | Cooling | |
|  4  | RAM | DDR5 ECC RDIMM |  4  | Memory | Configurable 1–24 DIMMs |
|  5  | SSD | 1 TB NVMe |  1  | Storage | Capacity configurable |
|  6  | M.2 heatsink | — |  1  | Cooling | |
|  7  | GPU | NVIDIA RTX 4090 or 5090 |  8  | Graphics | 24 GB / 32 GB each — 192–256 GB total |
|  8  | MCIO cable | — | 16  | Cable | Two per GPU (x16 = 2× x8) |
|  9  | MCIO→PCIe adapter | — |  8  | Adapter | One per GPU |
| 10  | PSU | 2000 W CRPS |  4  | Power | 8000 W total |
| 11  | PSU board | Power distribution board |  1  | Power | |
| 12  | Motherboard power cable | Power-board-to-motherboard harness |  1  | Cable | 1 set |
| 13  | GPU power cable | 12V-2x6 / 12VHPWR, 600 W rated |  8  | Cable | One per GPU |
| 14  | Fan | Case fan | 12  | Cooling | |
| 15  | Fan hub | Fan control board |  1  | Cooling | |
| 16  | Chassis | 5U rack chassis kit |  1  | Housing | Ships complete — [housing prep](../docs/prepare-me.md) |

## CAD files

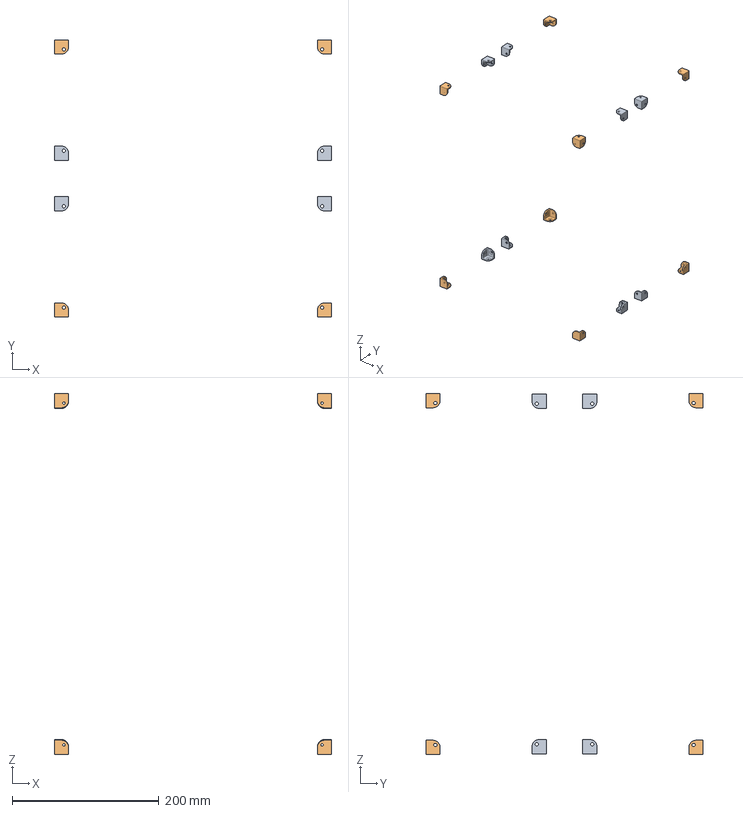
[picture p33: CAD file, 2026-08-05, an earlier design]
8x-5090/archive/step_models/Support.step
378.0 x 378.0 x 492.0 mm
Bat goc x 8
Bat goc (1) x 4
Bat goc (1)(Mirror)
Bat goc (1) (2)(Mirror)
Bat goc (1) (3)(Mirror)
Bat goc (1) (1)(Mirror)

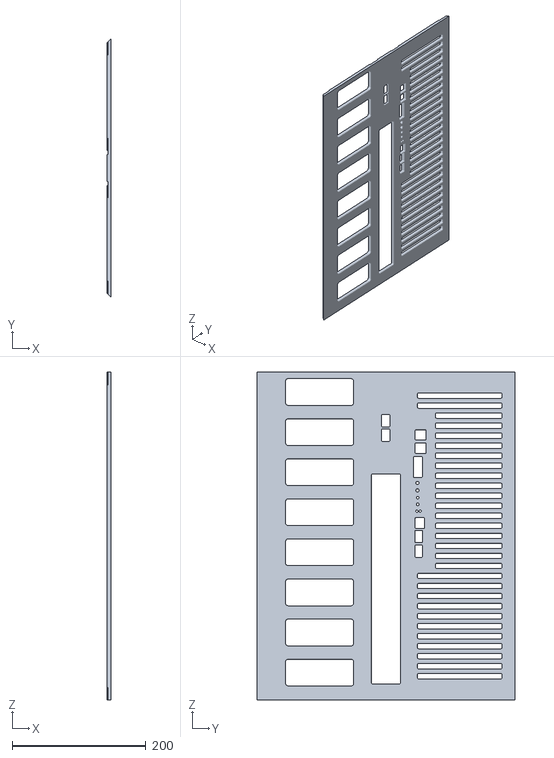
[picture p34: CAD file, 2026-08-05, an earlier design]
8x-5090/archive/stl-models/Part 4 - Back.stl
6.00 x 386.6 x 491.0

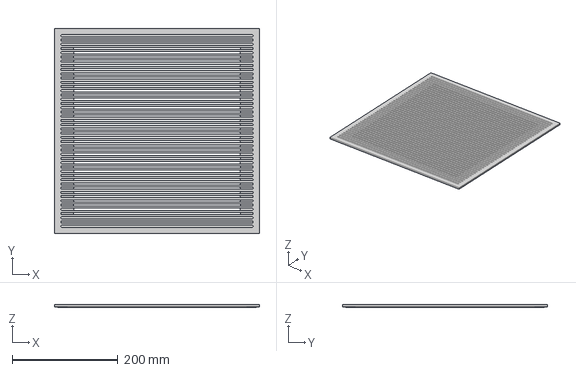
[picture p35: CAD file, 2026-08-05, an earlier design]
8x-5090/archive/step_models/Part 6 - Top v1.step
387.6 x 387.6 x 6.00 mm

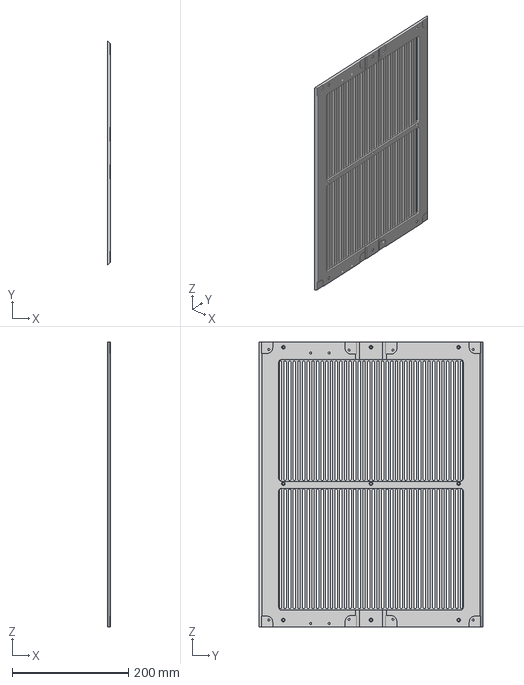
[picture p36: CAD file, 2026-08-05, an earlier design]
8x-5090/archive/step_models/Part 3 - Front.step
6.00 x 386.6 x 491.0 mm

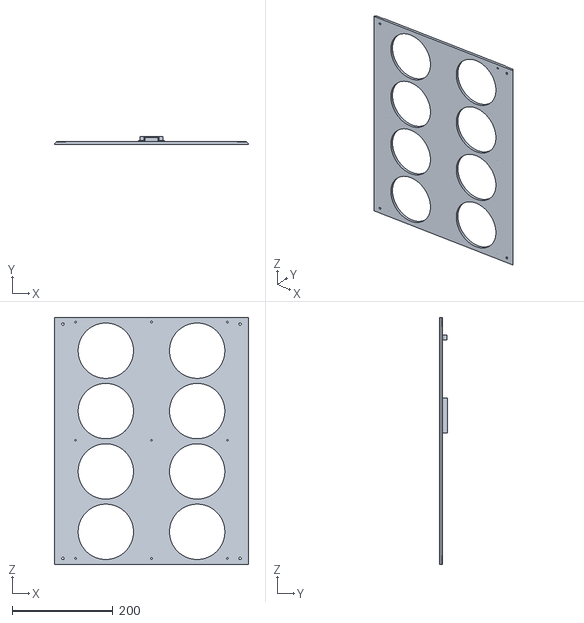
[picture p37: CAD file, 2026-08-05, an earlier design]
8x-5090/archive/stl-models/Part 7 - Side.stl
386.6 x 15.0 x 491.0

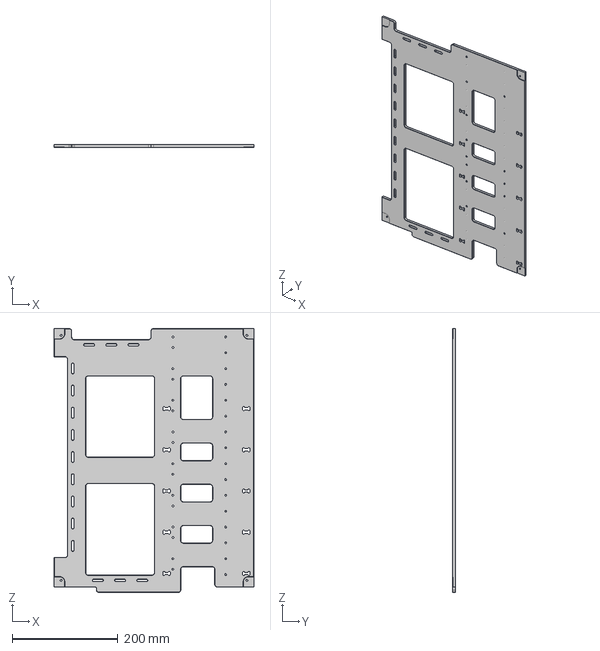
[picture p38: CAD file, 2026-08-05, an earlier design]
8x-5090/archive/step_models/Part 1 - GPU plate.step
378.0 x 6.00 x 500.0 mm

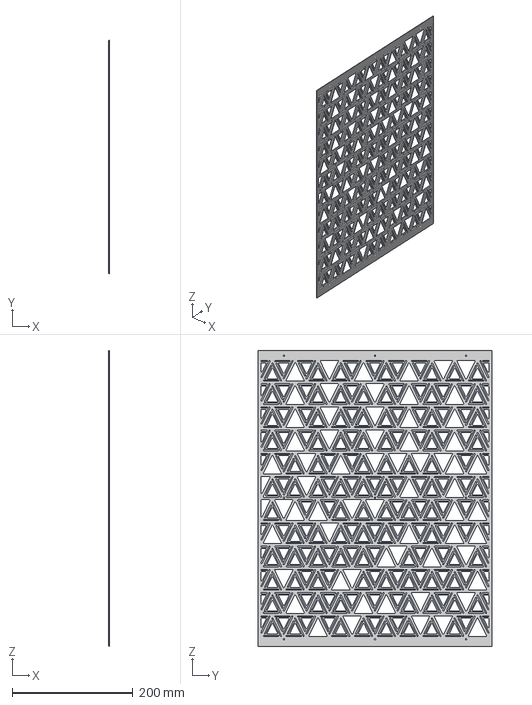
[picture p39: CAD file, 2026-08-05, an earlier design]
8x-5090/archive/step_models/Part 9 - Front cover.step
2.00 x 387.6 x 491.0 mm

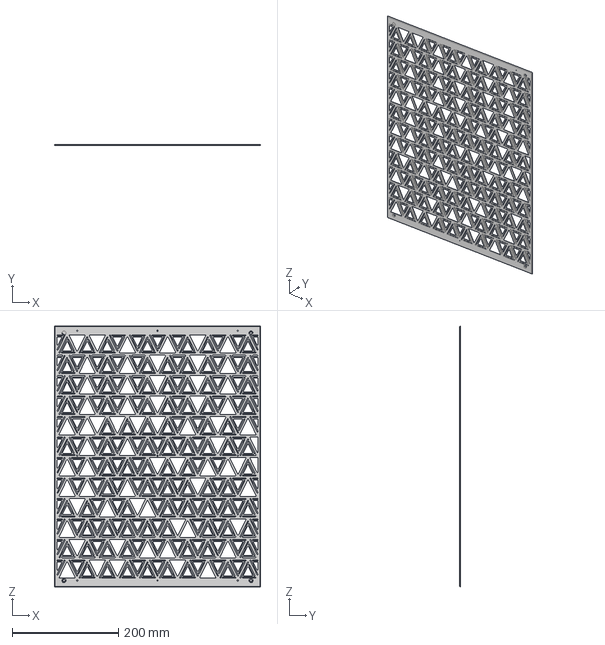
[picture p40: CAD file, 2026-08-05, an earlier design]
8x-5090/archive/step_models/Part 8 - Side cover.step
387.6 x 2.00 x 491.0 mm

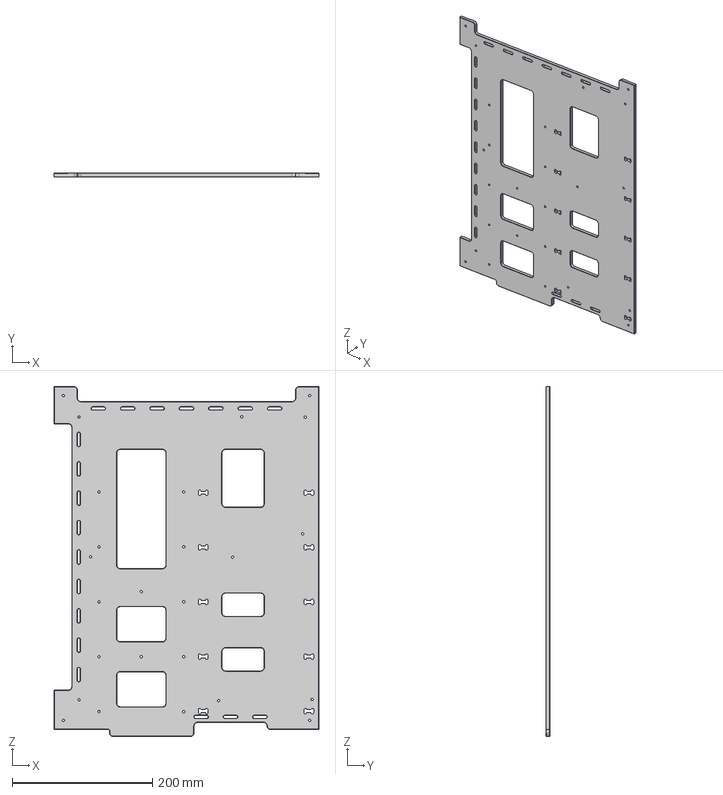
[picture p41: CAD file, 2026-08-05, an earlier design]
8x-5090/archive/step_models/Part 2 - CPU plate.step
378.0 x 6.00 x 500.0 mm

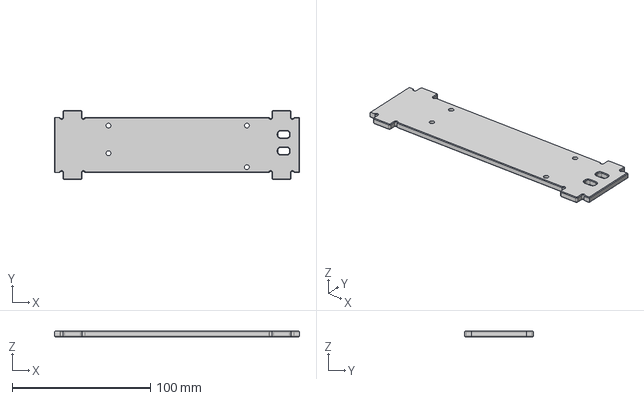
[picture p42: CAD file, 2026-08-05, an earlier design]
8x-5090/archive/step_models/Part 10 - PSU mount.step
177.0 x 50.0 x 4.00 mm

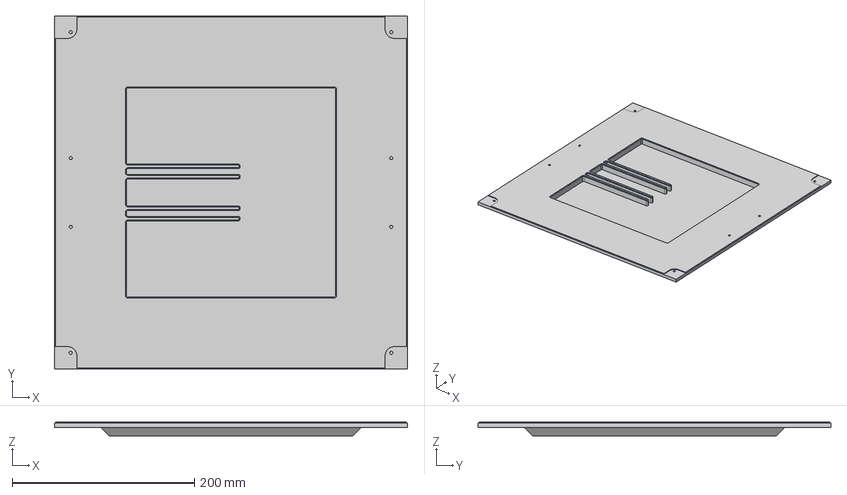
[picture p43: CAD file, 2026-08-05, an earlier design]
8x-5090/archive/step_models/Part 5 - Bottom.step
387.6 x 387.6 x 15.0 mm

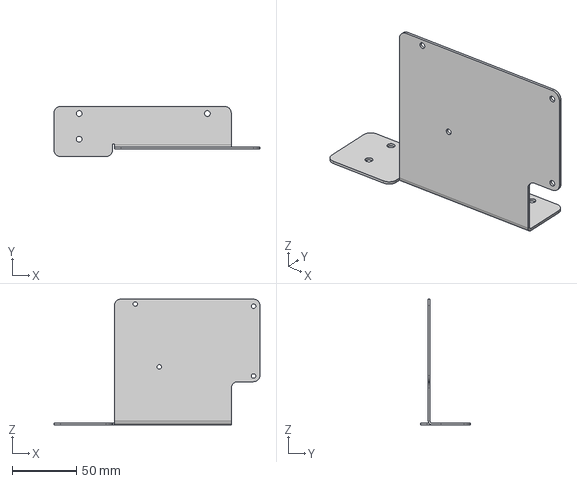
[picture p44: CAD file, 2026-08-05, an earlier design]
8x-5090/archive/step_models/Ethernet mount.step
160.6 x 39.0 x 98.0 mm

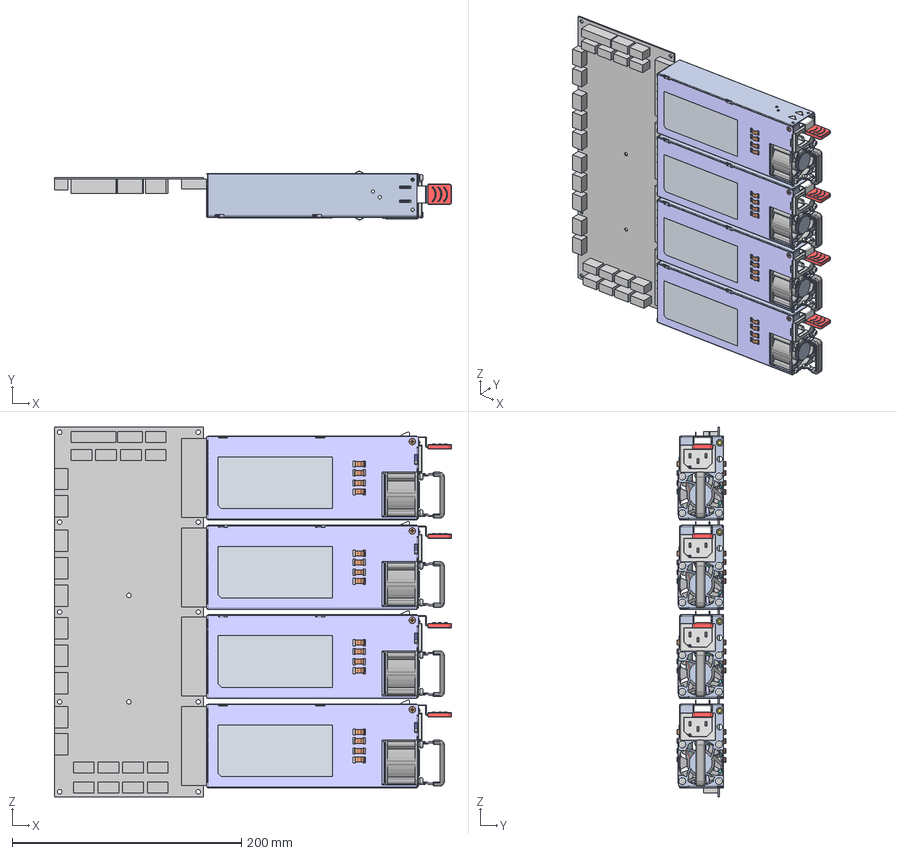
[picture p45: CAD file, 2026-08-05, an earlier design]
8x-5090/archive/step_models/PSU Board.step
346.6 x 42.5 x 323.0 mm
PSU_4 x 4
Board PSU

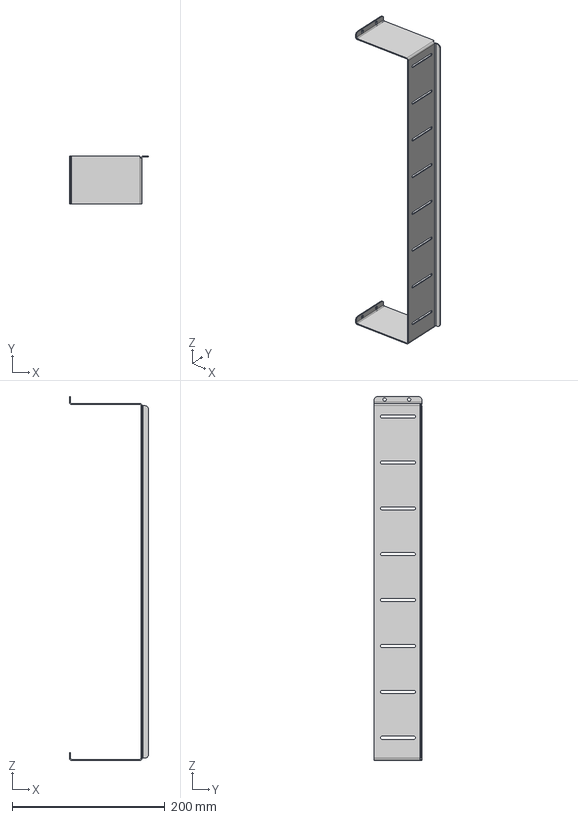
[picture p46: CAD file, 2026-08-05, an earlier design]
8x-5090/archive/step_models/GPU mount.step
103.5 x 63.0 x 476.0 mm

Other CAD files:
8x-5090/archive/stl-models/Part 6 - Top.stl
8x-5090/archive/stl-models/Ethernet mount.stl
8x-5090/archive/stl-models/GPU mount.stl
8x-5090/archive/stl-models/Part 10 - PSU mount.stl
8x-5090/archive/stl-models/Part 3 - Front.stl
8x-5090/archive/stl-models/Part 5 - Bottom.stl
8x-5090/archive/stl-models/Part 8 - Side cover.stl
8x-5090/archive/stl-models/Part 9 - Front cover.stl

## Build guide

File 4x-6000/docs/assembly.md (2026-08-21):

# Assembly

Order of assembly for one 4× RTX PRO 6000 machine — the Pro WS W790E-SAGE SE board, one Xeon w5-3423, and four RTX PRO 6000 Blackwell cards in the milled aluminium cube. Step photos are added as the build is documented.

| Step | Description |
|:----:|:---|
|  1 | Prepare the housing parts — the [housing prep](prepare-me.md). |
|  2 | Attach the first side to the base. |
|  3 | Attach the other side to the base. |
|  4 | Attach the top to the housing. |
|  5 | Attach the brass hex standoffs to the back side. |
|  6 | Mount the four PCIe 5.0 risers to the mount plate. |
|  7 | Attach the fan plate to the mount. |
|  8 | Mount the fans to the fan plate and the base. |
|  9 | Place the motherboard on the mount. |
|  10  | Screw the motherboard down to the mount. |
|  11  | Connect the four PCIe risers to the motherboard. |
|  12  | Seat the four RTX PRO 6000s in the riser slots. |
|  13  | Screw the GPUs down to the mount. |
|  14  | Attach the two power supplies to the base. |
|  15  | Connect the cables on the PSU side. |
|  16  | Connect the ATX cable to the motherboard. |
|  17  | Connect the EPS / CPU power connectors to the motherboard. |
|  18  | Connect the CPU fan and the fan controller to the motherboard. |
|  19  | Connect the 12V-2x6 power cables to the four GPUs. |
|  20  | All electronics installed. |
|  21  | Attach one side panel of the housing. |
|  22  | Attach the other side panel. |
|  23  | Fit the final panel — done. |

---

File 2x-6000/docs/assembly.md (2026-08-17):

# Assembly

Same housing and the same 23 steps as the [2× 5090](../../2x-5090/README.md) — print the [STLs](../../2x-5090/stl-models) or CNC the [STEPs](../../2x-5090/step_models). Only the cards differ. Steps 12, 13, 20, and 23 are photographed from this build; the rest are from the 2× 5090 until the remaining 2× 6000 shots are in.

| Step | Description | Image |
|---|---|---|
| 1 | Prepare the housing parts. |  |
| 2 | Attach the first side to the base. |  |
| 3 | Attach the other side to the base. |  |
| 4 | Attach the top to the housing. |  |
| 5 | Attach the brass hex standoffs to the back side. |  |
| 6 | Mount the PCIe risers to the mount plate. |  |
| 7 | Attach the fan plate to the mount. |  |
| 8 | Mount the fans to the fan plate. |  |
| 9 | Place the motherboard on the mount. |  |
| 10 | Screw the motherboard down to the mount. |  |
| 11 | Connect the PCIe risers to the motherboard. |  |
| 12 | Seat the GPUs in the riser slots. |  |
| 13 | Screw the GPUs down to the mount. |  |
| 14 | Attach the PSU to the base. |  |
| 15 | Connect the cables on the PSU side. |  |
| 16 | Connect the ATX cable to the motherboard. |  |
| 17 | Connect the 8-pin connector to the motherboard. |  |
| 18 | Connect the CPU fan to the motherboard. |  |
| 19 | Connect the 12-pin power cables to the GPUs. |  |
| 20 | All electronics installed. |  |
| 21 | Attach one side panel of the housing. |  |
| 22 | Attach the other side panel. |  |
| 23 | Fit the final panel — done. |  |

---

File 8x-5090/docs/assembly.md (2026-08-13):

# Assembly

Order of assembly for one 5U server — the GENOA2D24G-2L+ board, two EPYC 9004 CPUs, and eight RTX 5090 GPUs in the 5U rack chassis. Step photos are added as the build is documented.

| Step | Description | Image |
|:----:|:---|:---|
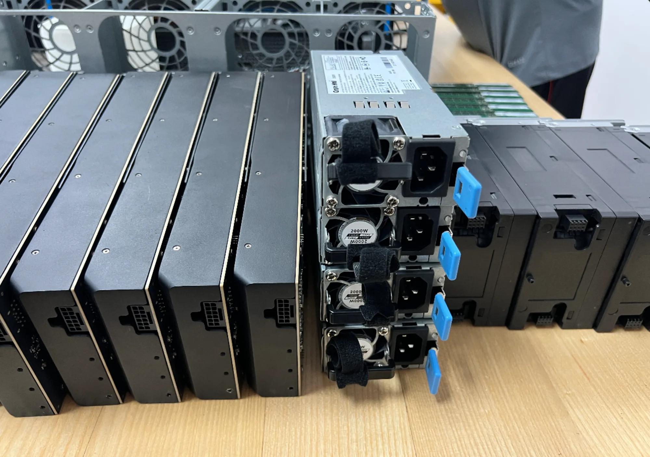
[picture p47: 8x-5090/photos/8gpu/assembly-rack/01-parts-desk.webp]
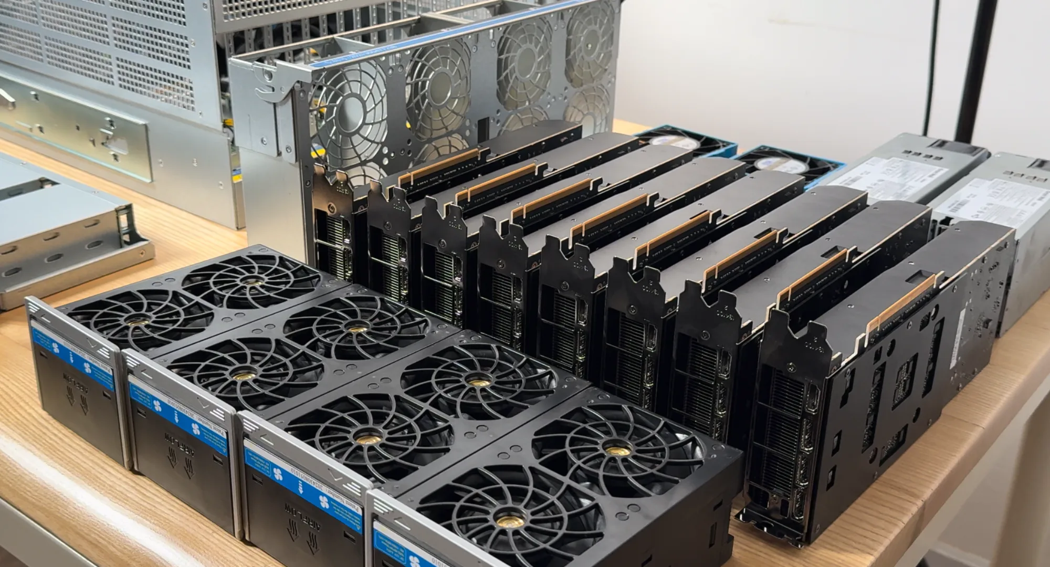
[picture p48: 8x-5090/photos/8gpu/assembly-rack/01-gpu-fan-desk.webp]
|  1 | Work through the [component checklist](prepare-ee.md) and lay every part out on the build desk. |   |
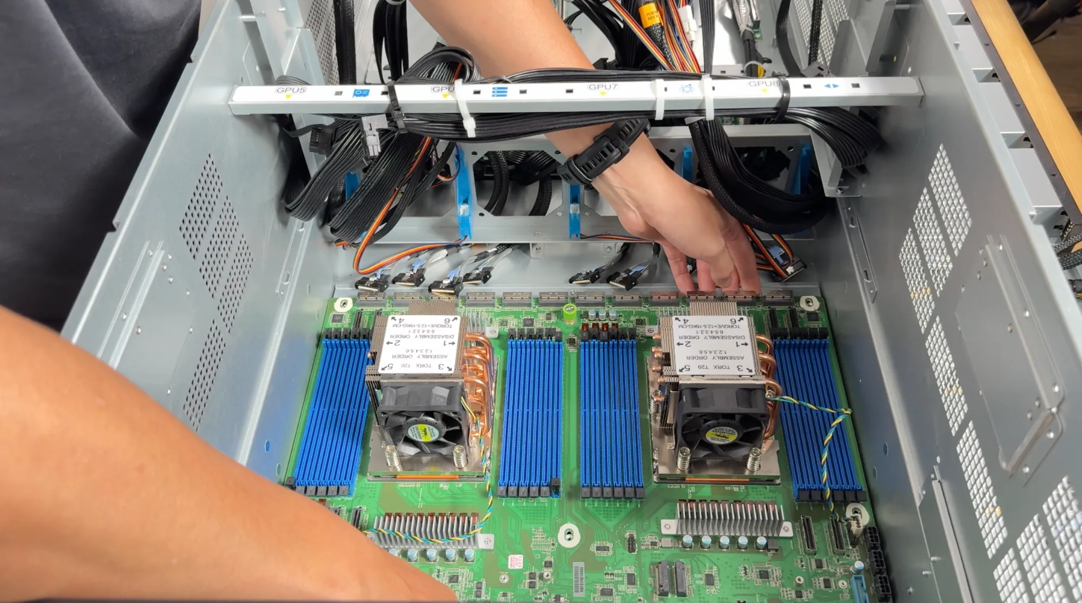
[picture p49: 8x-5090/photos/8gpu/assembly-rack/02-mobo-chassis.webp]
|  2 | Seat the motherboard in the chassis and secure it with the standoffs and screws. |  |
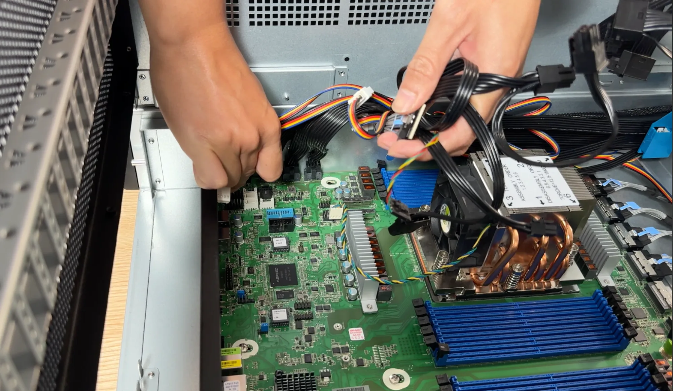
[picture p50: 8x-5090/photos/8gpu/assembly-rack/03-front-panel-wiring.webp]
|  3 | Connect the power button and the front-panel wiring to the motherboard headers. |  |
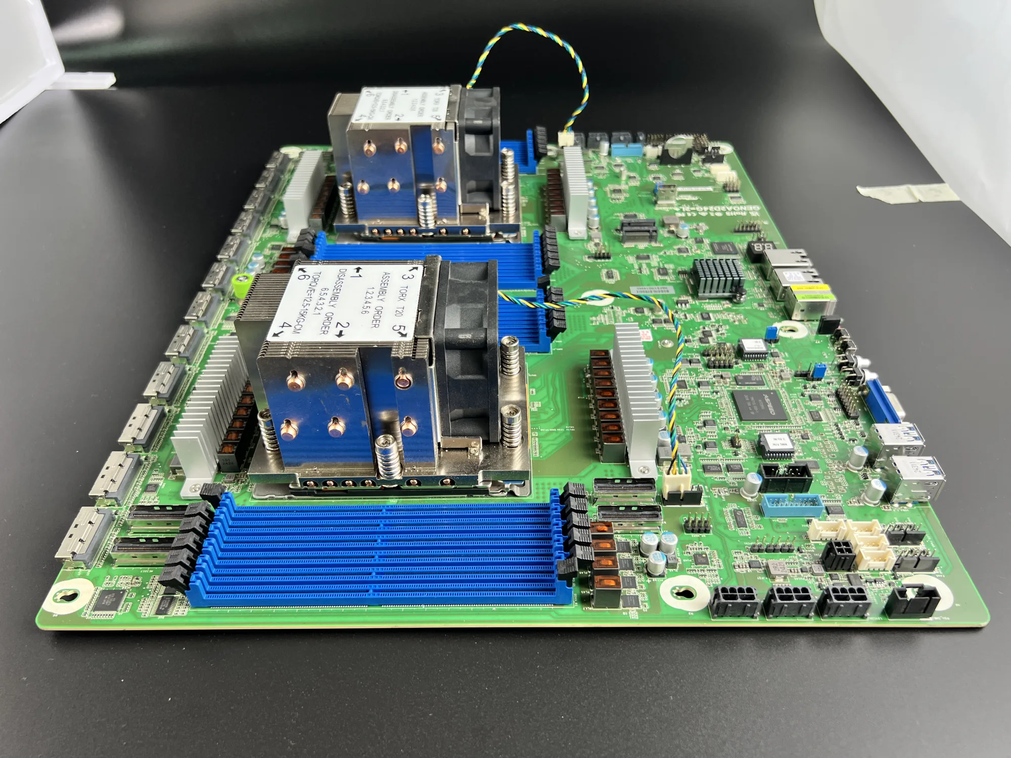
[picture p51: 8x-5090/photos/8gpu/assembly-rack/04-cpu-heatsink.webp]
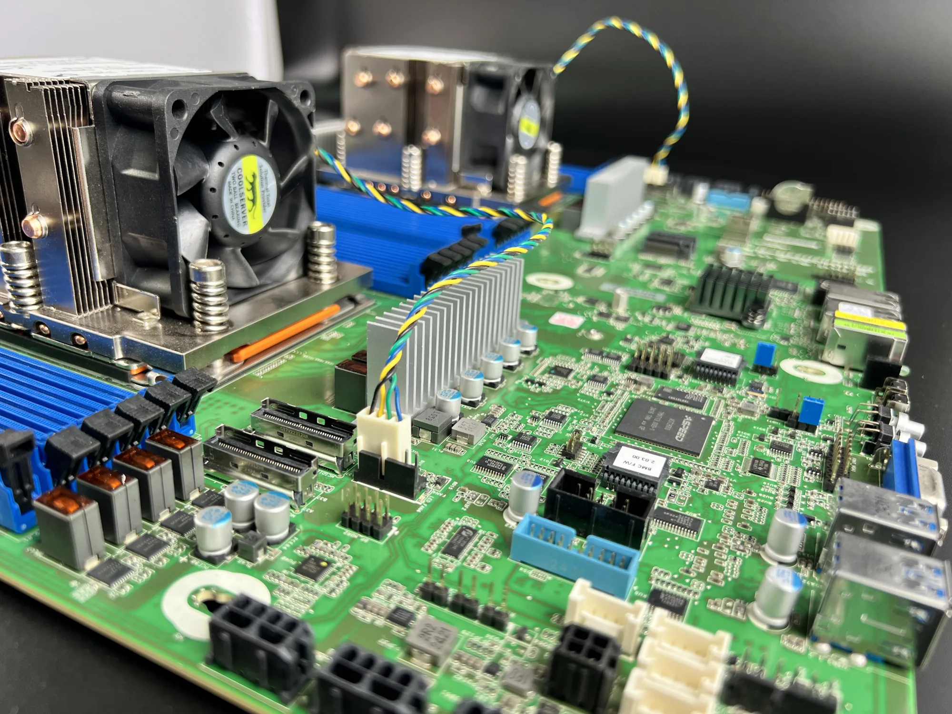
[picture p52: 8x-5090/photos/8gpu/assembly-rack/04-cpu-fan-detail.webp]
|  4 | Install both CPUs into the SP5 sockets, then mount the CPU heatsinks. |   |
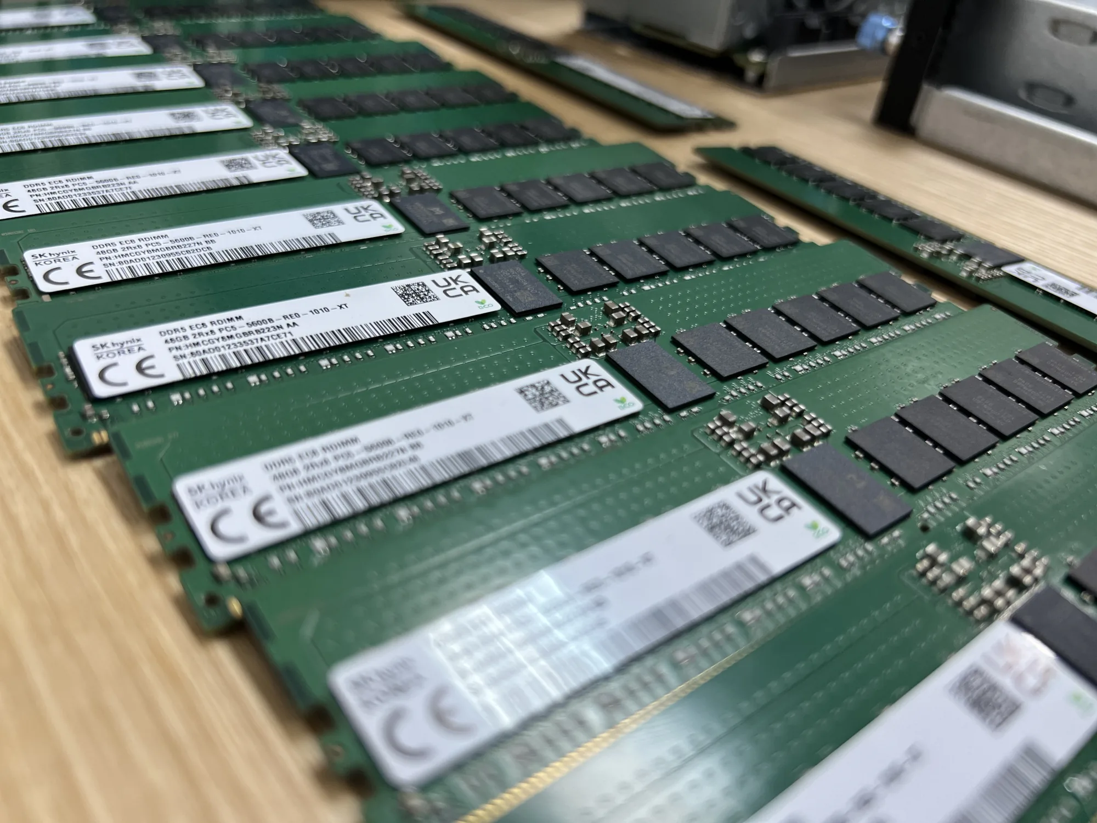
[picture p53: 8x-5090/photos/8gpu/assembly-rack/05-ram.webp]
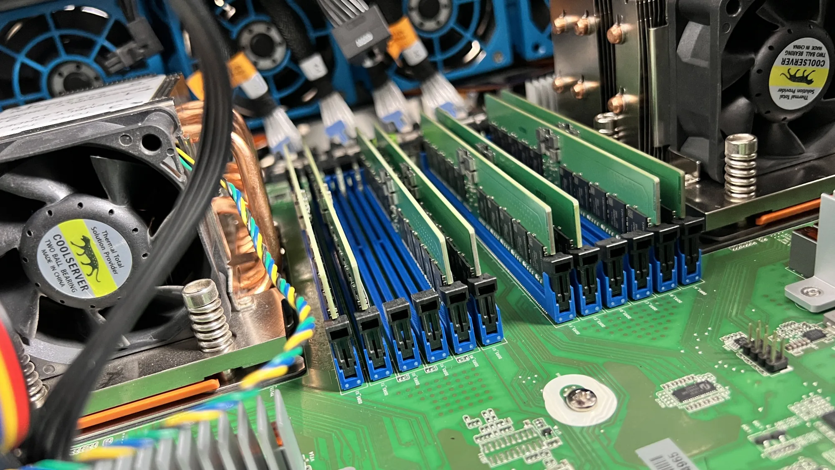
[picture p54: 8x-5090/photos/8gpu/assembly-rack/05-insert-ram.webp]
|  5 | Populate the DDR5 ECC RDIMMs, following the board's DIMM population order. |   |
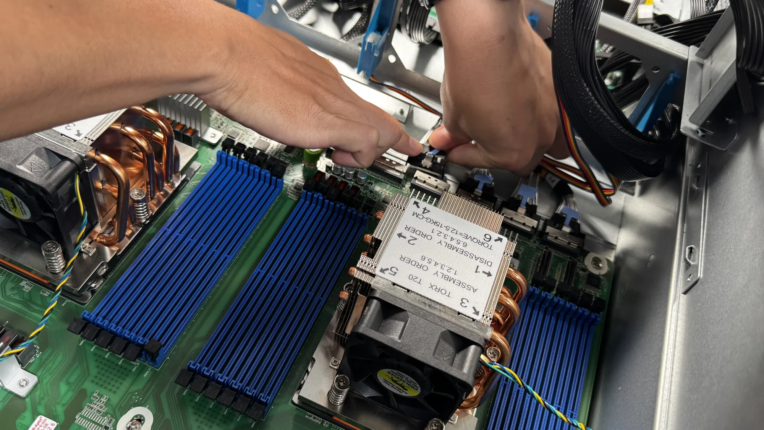
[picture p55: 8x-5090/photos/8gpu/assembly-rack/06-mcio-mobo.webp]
|  6 | Connect the MCIO cables to the motherboard — two per GPU (x16 = 2× x8). |  |
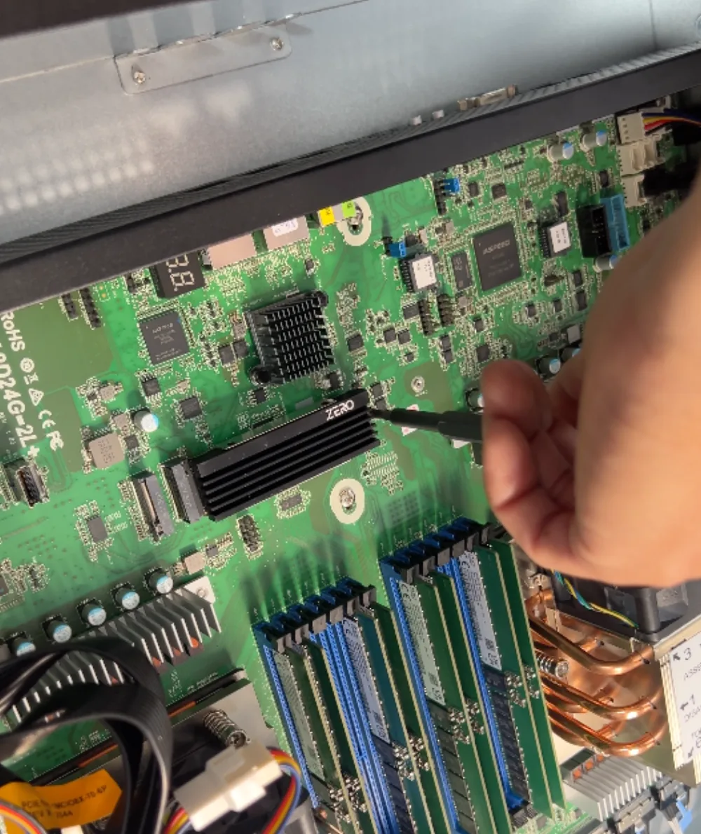
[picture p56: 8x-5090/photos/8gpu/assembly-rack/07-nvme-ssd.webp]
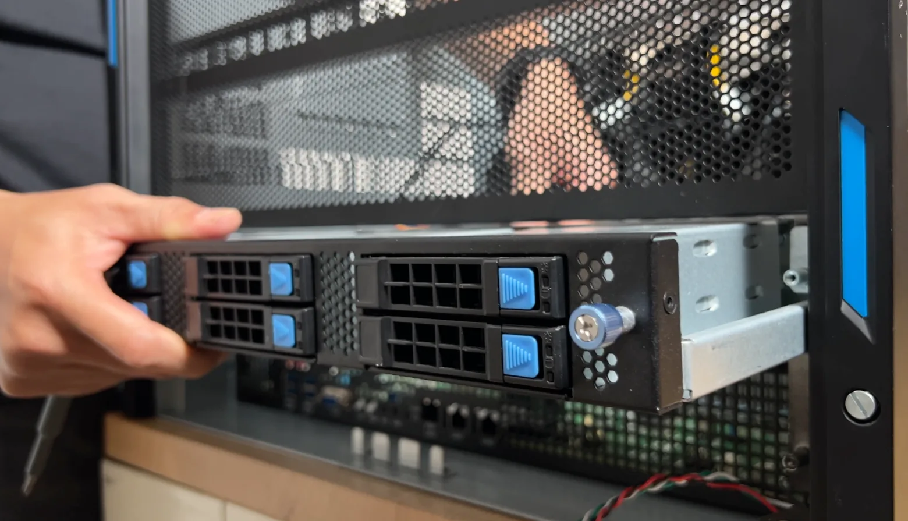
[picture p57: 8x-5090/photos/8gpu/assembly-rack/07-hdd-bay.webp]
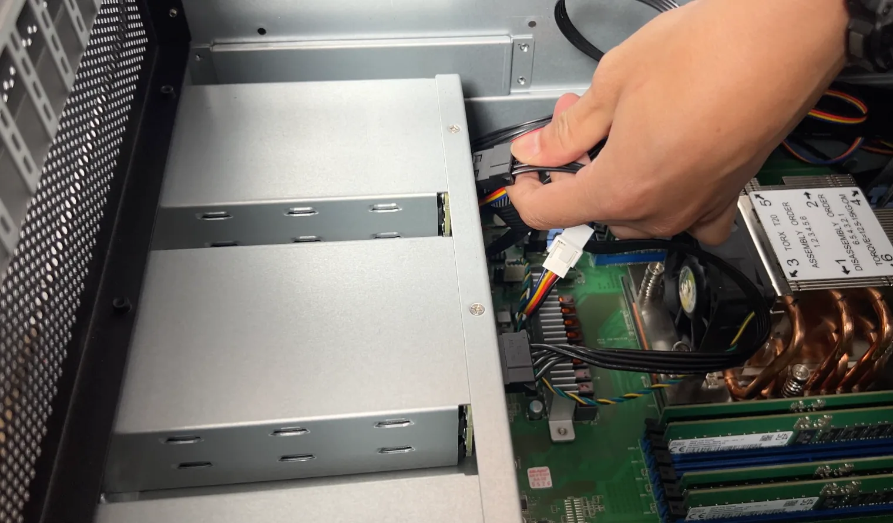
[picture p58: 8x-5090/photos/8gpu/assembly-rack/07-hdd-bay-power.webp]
|  7 | Install the NVMe SSD, then the HDD bay and drive panel, and connect the bay's power cable. |    |
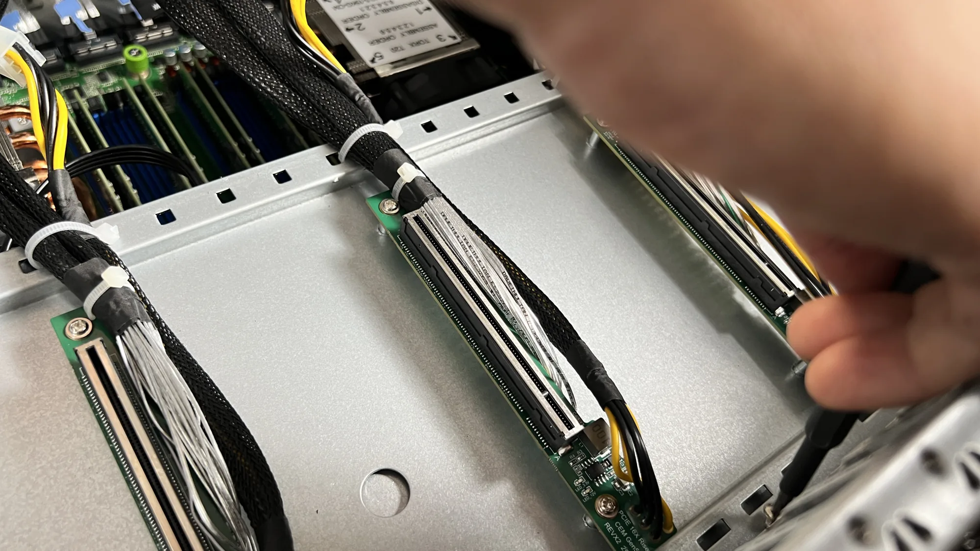
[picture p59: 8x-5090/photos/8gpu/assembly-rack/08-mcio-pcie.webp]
|  8 | Mount the MCIO→PCIe x16 adapters onto the chassis mounts — one per GPU slot — and lay out the numbered GPU rails. |   |
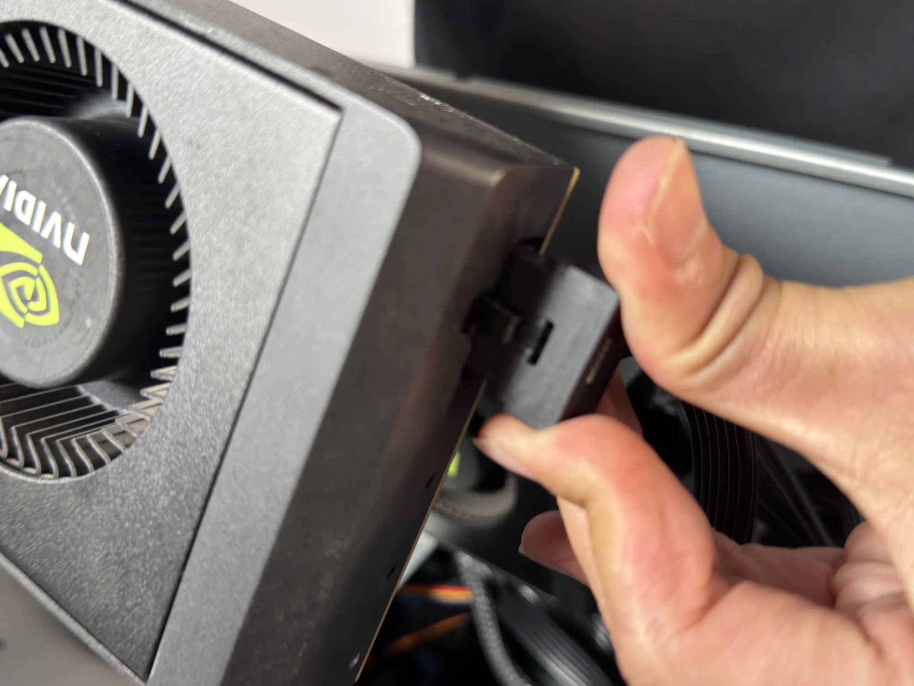
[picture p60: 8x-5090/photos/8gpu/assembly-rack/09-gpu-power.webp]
|  9 | Install the eight RTX 5090 GPUs, secure each one, and connect the 12V-2x6 power. |   |
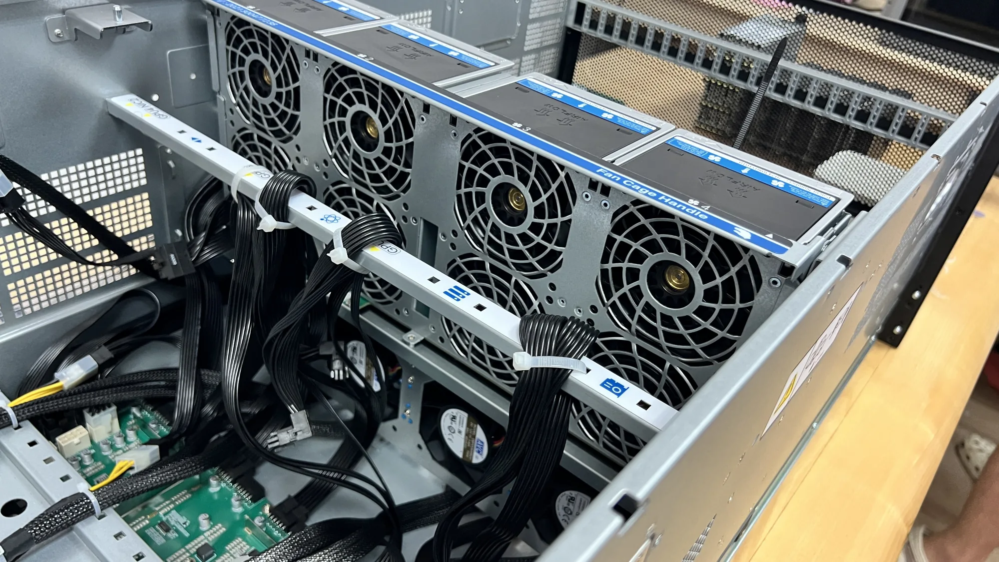
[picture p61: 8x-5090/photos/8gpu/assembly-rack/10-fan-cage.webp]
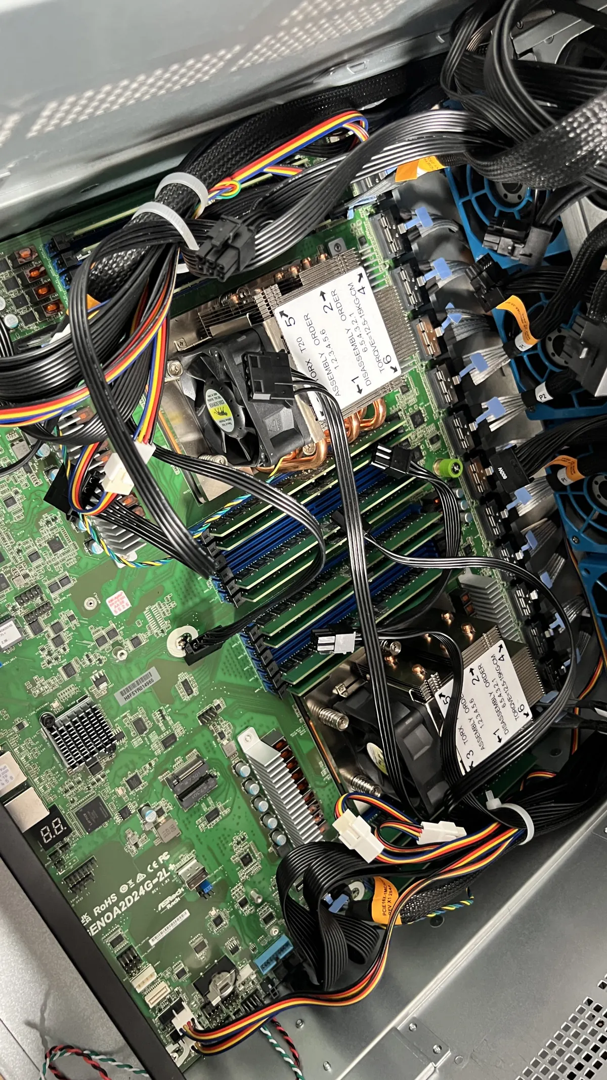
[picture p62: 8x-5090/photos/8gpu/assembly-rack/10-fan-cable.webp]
|  10  | Slide the fan cages into the front and rear blocks, then connect them to the motherboard. |    |
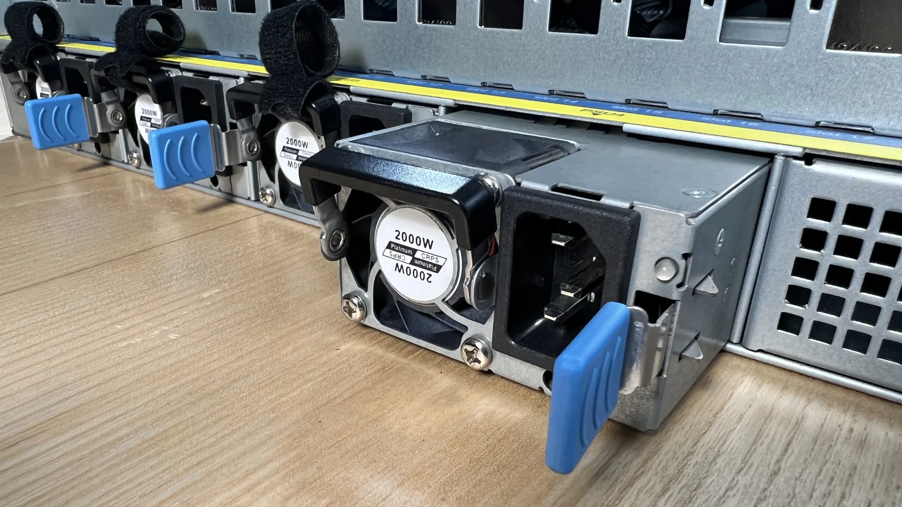
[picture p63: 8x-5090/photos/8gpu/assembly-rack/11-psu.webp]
|  11  | Slide the CRPS PSUs into the rear bay and connect them to the power board. |   |
|  12  | Power on and test — all eight cards detected, full VRAM, full PCIe link width. See [the setup guide](../../setup.md#gpu-testing). | |
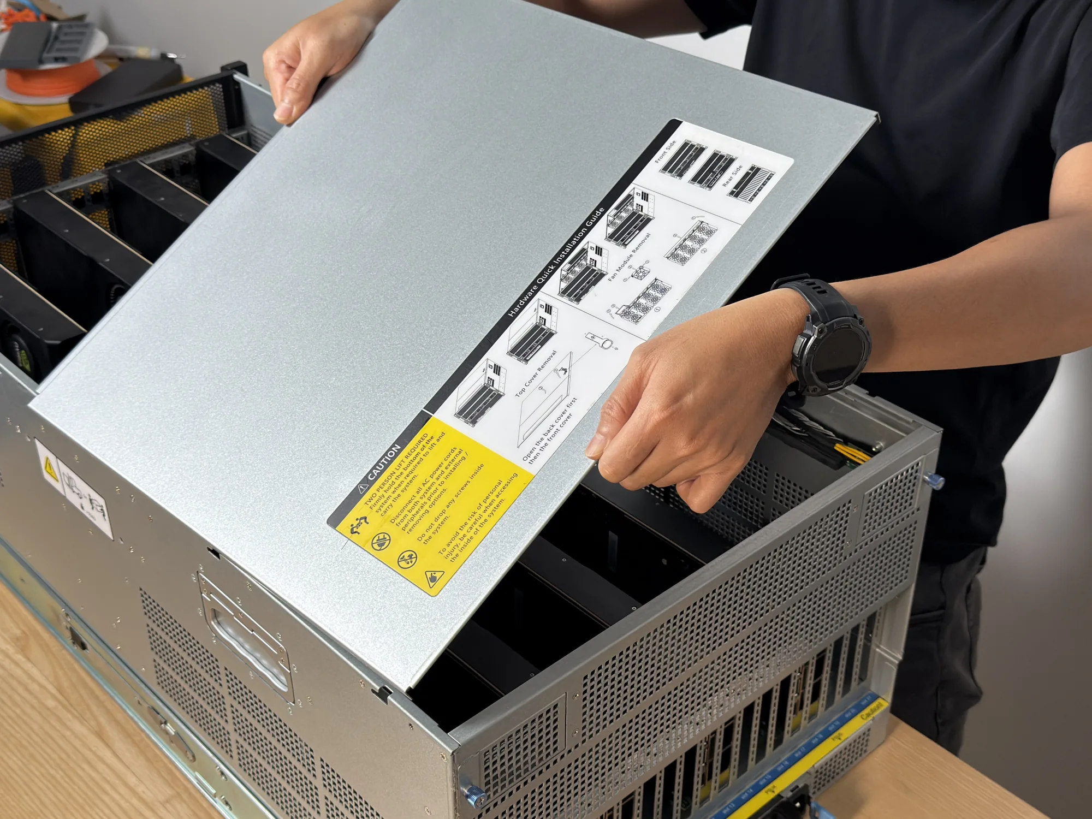
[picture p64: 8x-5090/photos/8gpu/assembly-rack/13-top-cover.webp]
|  13  | Fit the top cover and close the chassis for the rack. Two-person lift — the back cover goes on before the front. |  |

---

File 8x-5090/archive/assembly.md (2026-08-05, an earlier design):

# Assembly — CNC desktop case (archived)

> **Archived.** These 39 steps build the original CNC-milled desktop tower. The 8× 5090 now ships in a 5U rack chassis — see the [current assembly guide](../docs/assembly.md).

| Step | Description | Image |
|---|---|---|
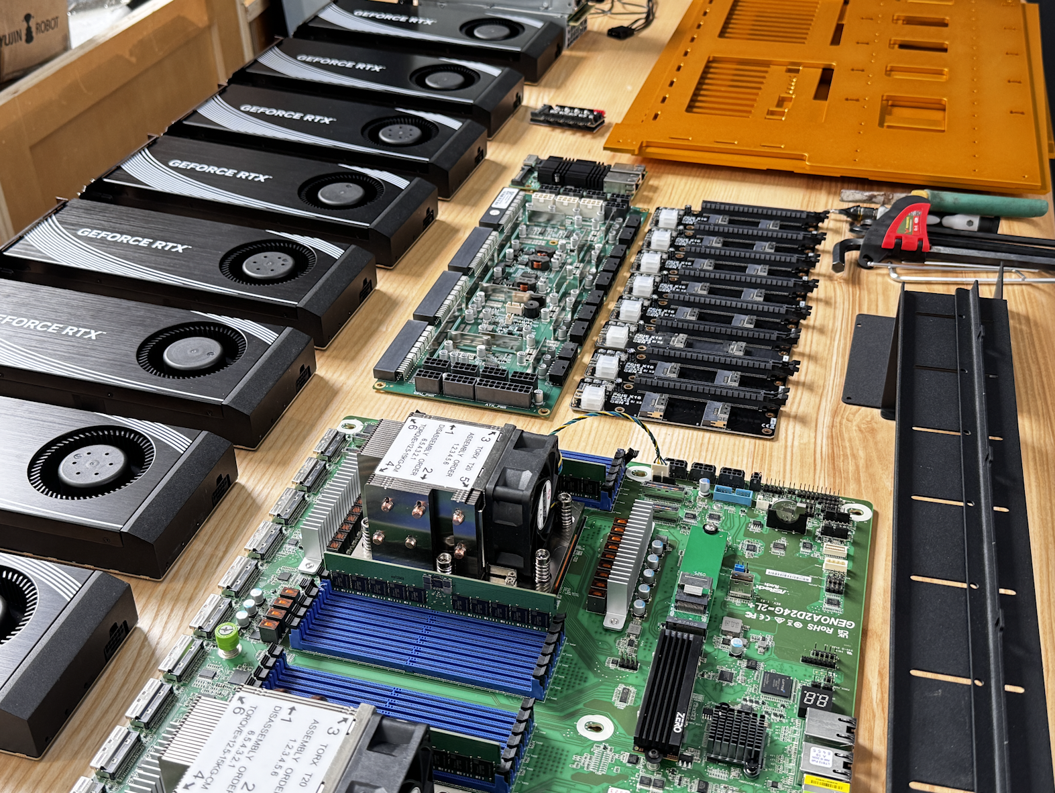
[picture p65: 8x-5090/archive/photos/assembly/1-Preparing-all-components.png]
| 1 | Prepare all components. |  |
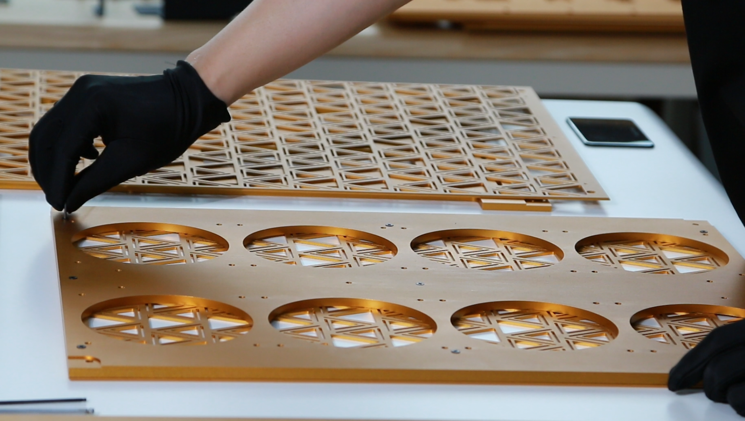
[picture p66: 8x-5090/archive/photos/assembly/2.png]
| 2 | Assemble “Part 7 – Side” and “Part 8 – Side Cover” together. Repeat for the other side. |  |
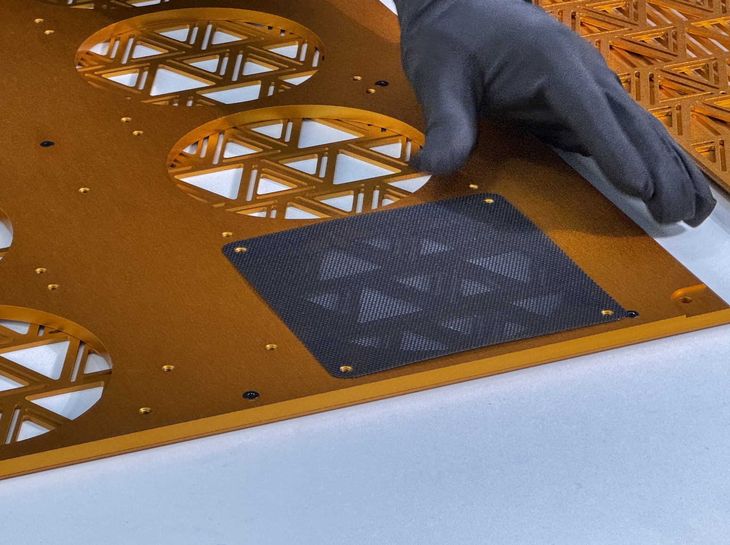
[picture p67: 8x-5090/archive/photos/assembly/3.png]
| 3 | Install the dust filter. |  |
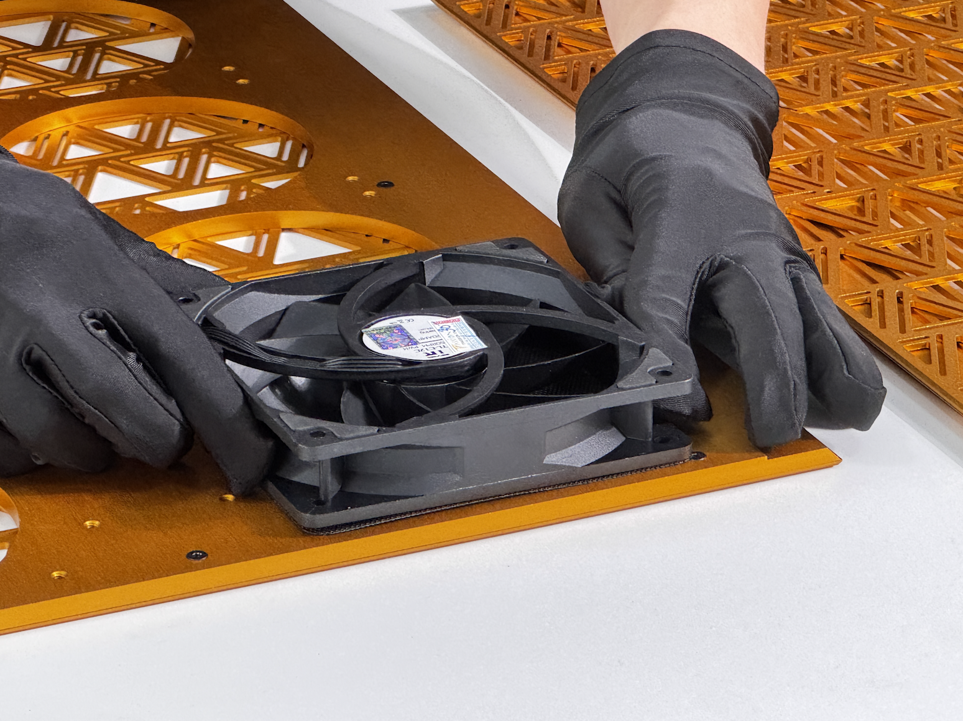
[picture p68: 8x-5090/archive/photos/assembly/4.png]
| 4 | Assemble the 120 mm × 120 mm fan. |  |
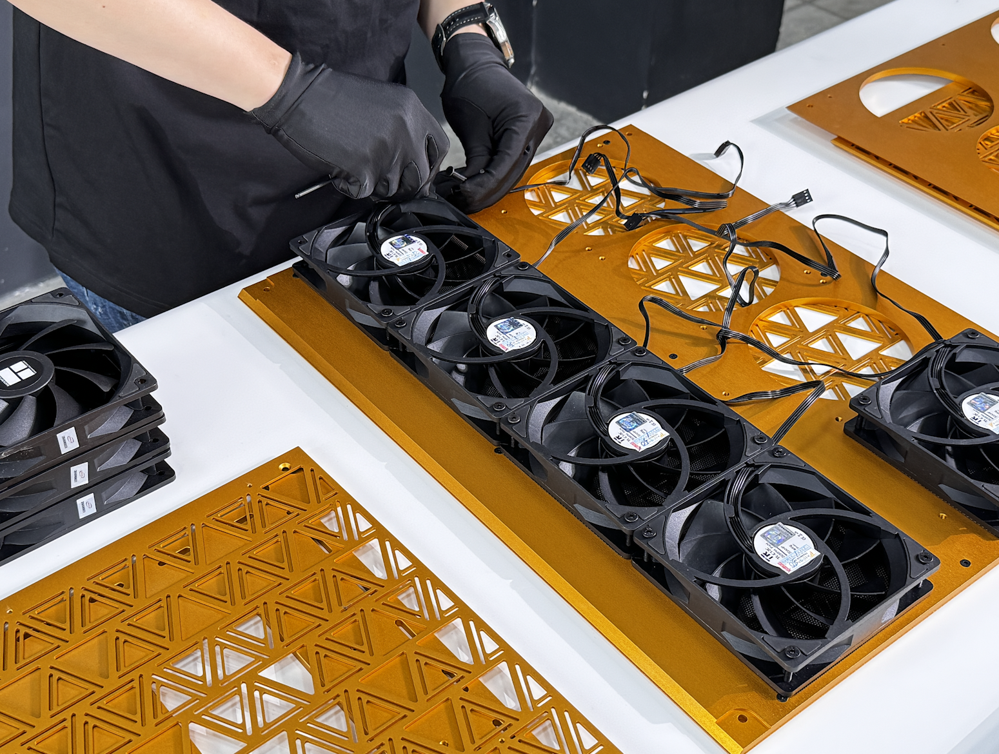
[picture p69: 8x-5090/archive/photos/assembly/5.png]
| 5 | Install the remaining fans. |  |
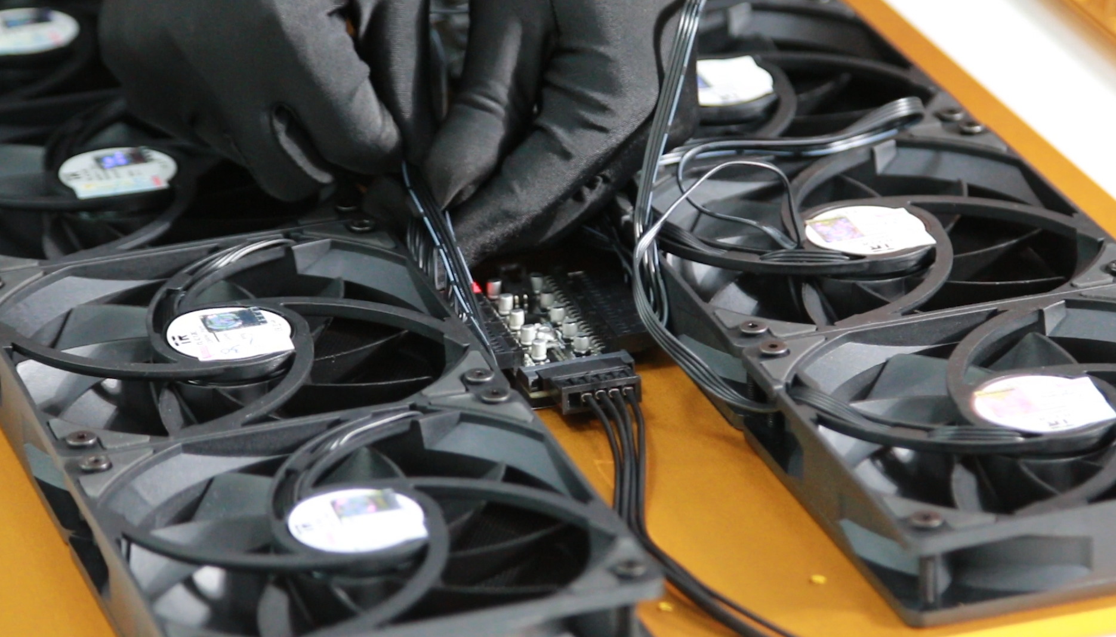
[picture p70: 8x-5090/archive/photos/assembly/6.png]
| 6 | Connect all fans to the control board. |  |
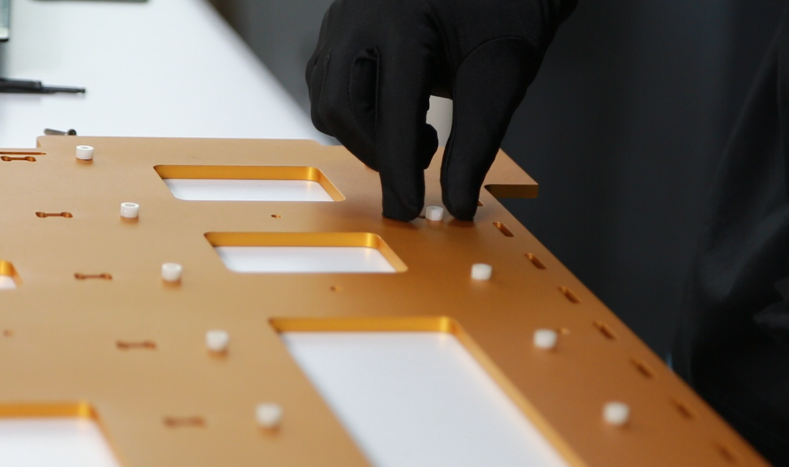
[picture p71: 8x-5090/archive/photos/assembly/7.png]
| 7 | Place plastic spacers in position on “Part 2 – CPU Plate”. |  |
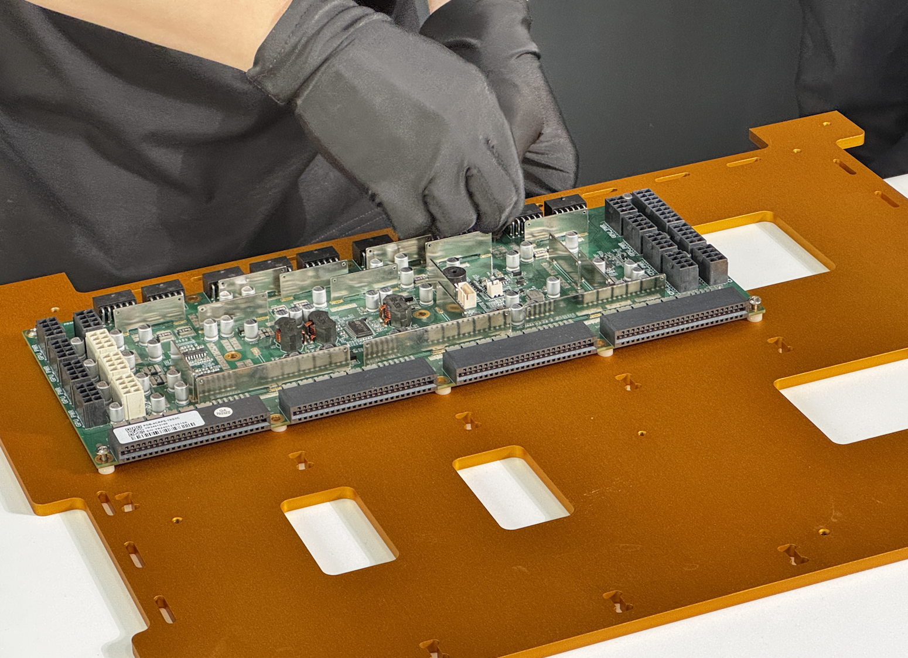
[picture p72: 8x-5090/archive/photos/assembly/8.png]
| 8 | Fix the PSU board to “Part 2 – CPU Plate”. |  |
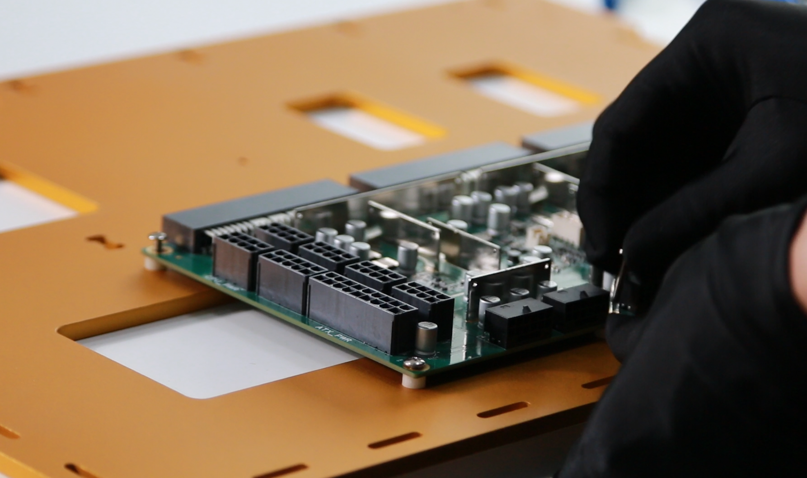
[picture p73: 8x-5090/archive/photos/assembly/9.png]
| 9 | Insert all screws, but do not tighten them yet. |  |
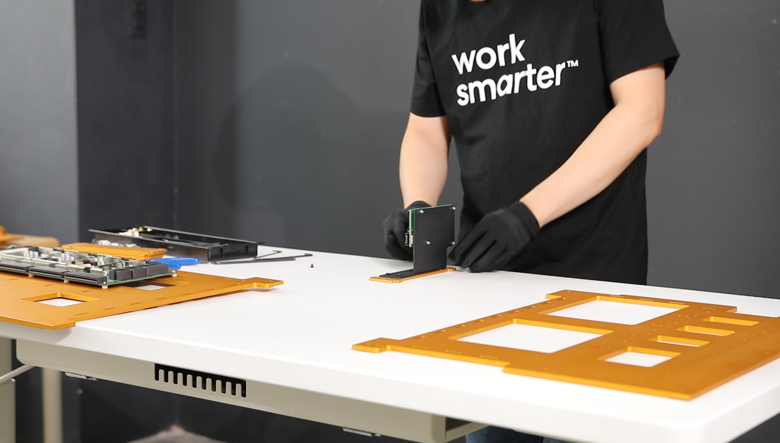
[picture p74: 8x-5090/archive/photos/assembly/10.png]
| 10 | Assemble the Ethernet board into “Part 10 – PSU Mount”. |  |
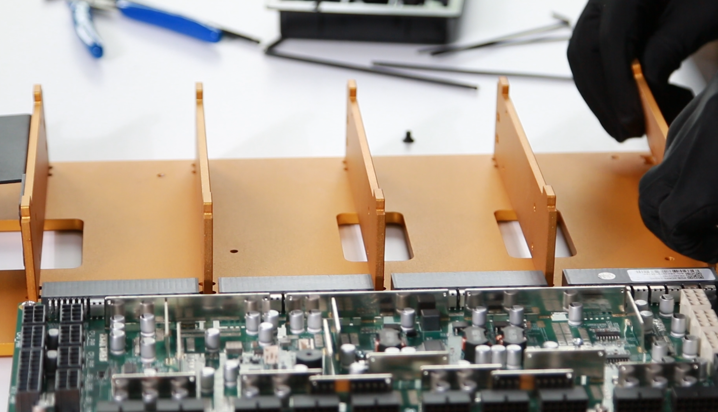
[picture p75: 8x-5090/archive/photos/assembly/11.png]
| 11 | Place “Part 10 – PSU Mount” into position. |  |
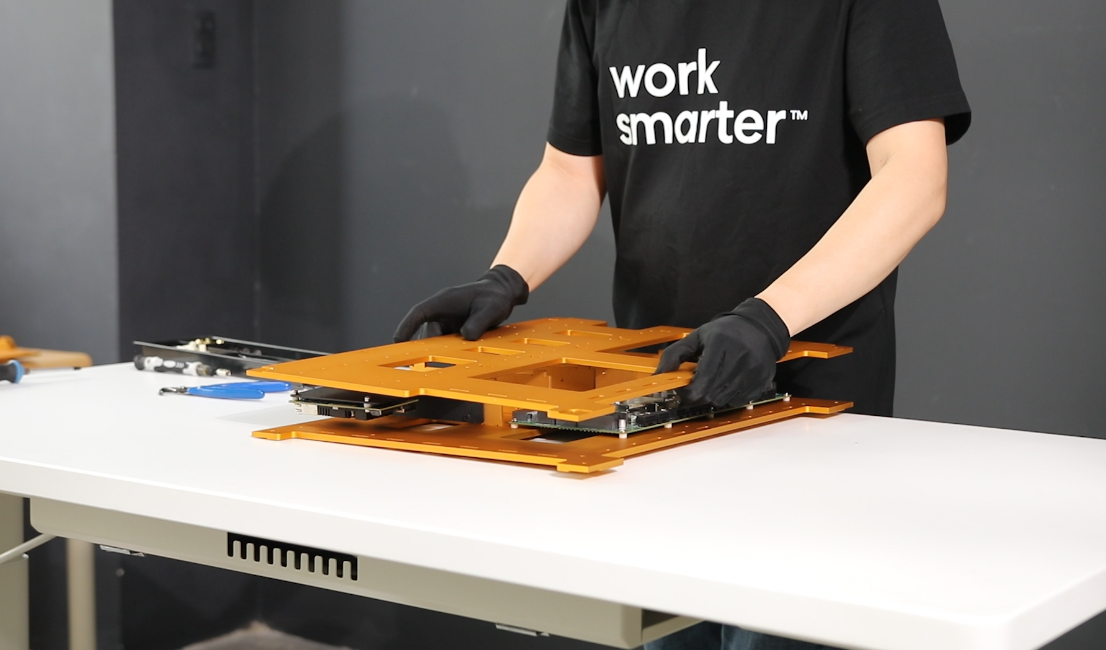
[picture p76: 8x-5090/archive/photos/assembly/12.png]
| 12 | Place “Part 1 – GPU Plate” on top. |  |
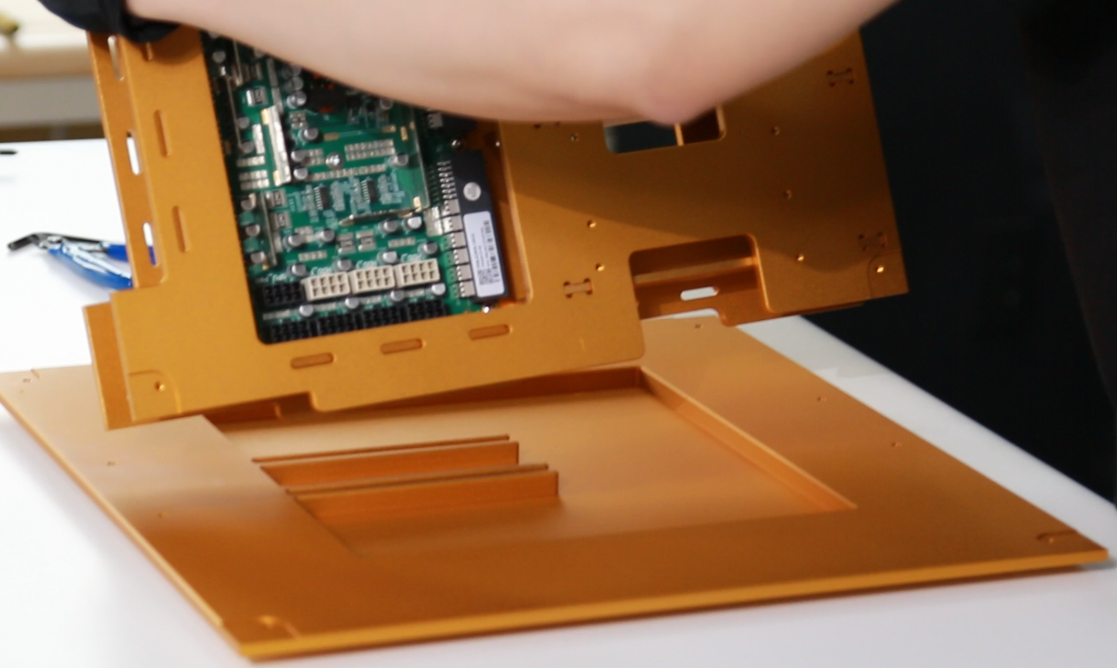
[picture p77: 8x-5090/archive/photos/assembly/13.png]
| 13 | Place all middle parts onto “Part 5 – Bottom”. |  |
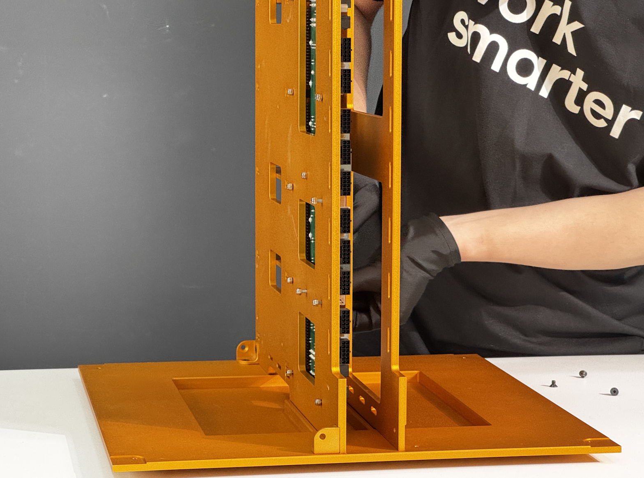
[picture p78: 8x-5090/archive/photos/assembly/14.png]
| 14 | Place all support mounts into position. |  |
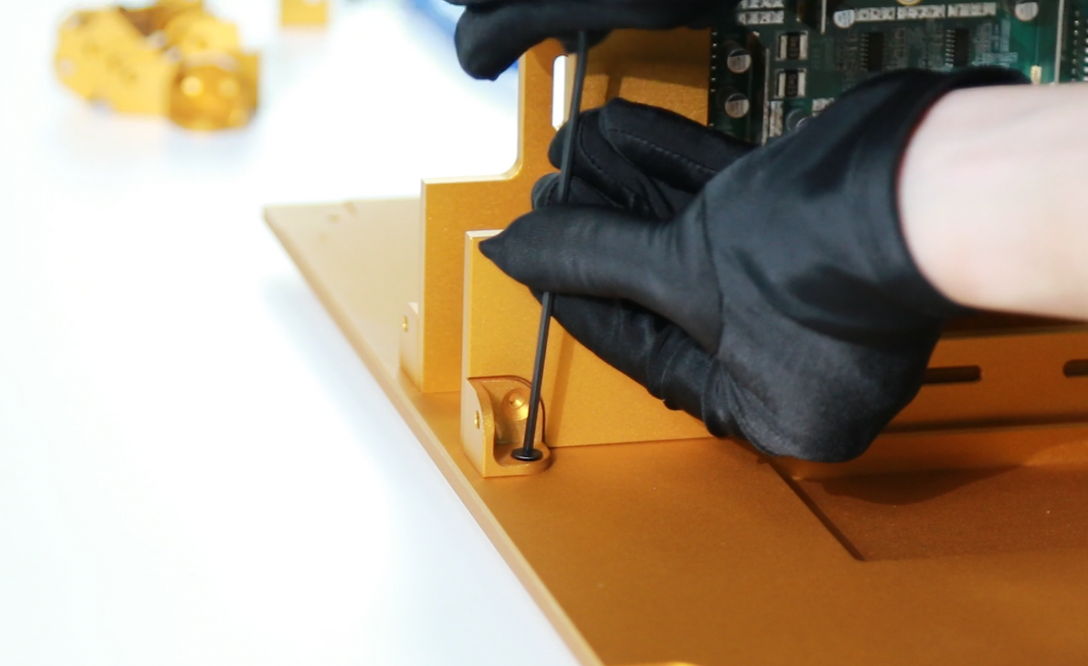
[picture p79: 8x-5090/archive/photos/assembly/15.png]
| 15 | Secure with M4 × 8 mm screws. |  |
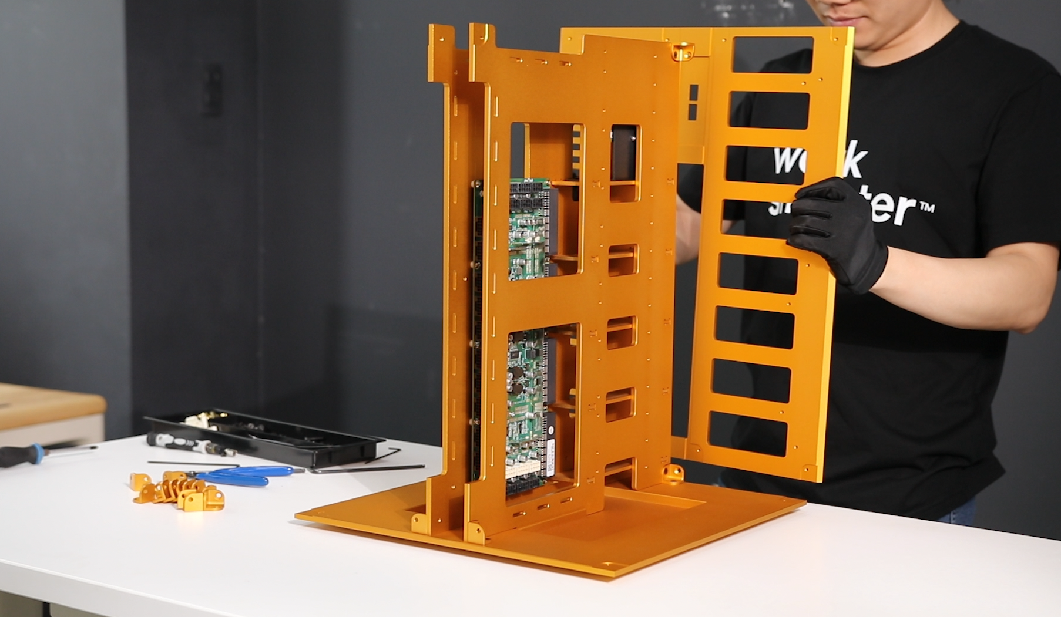
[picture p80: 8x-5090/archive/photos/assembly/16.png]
| 16 | Place “Part 4 – Back” into position and secure it with M4 screws. |  |
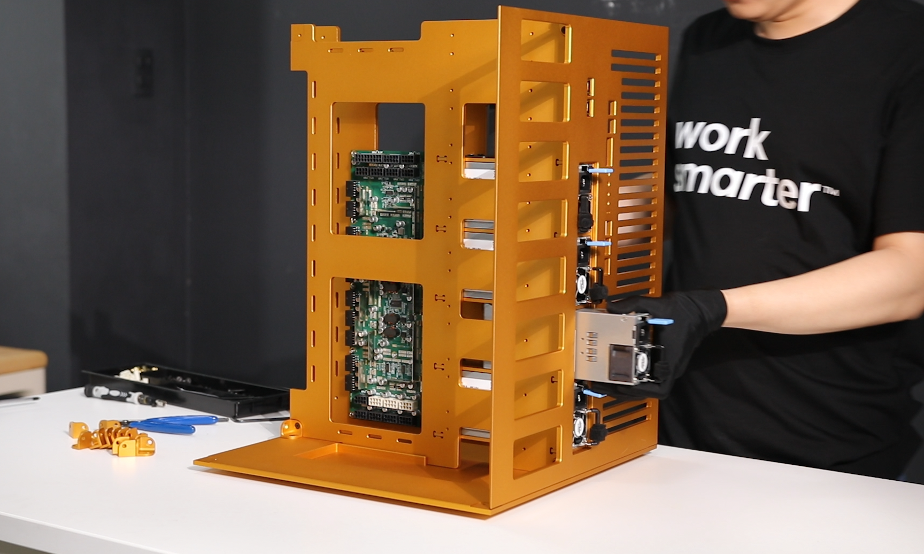
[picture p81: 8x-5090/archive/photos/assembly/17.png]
| 17 | Install all four PSUs into position and connect them to the PSU board. |  |
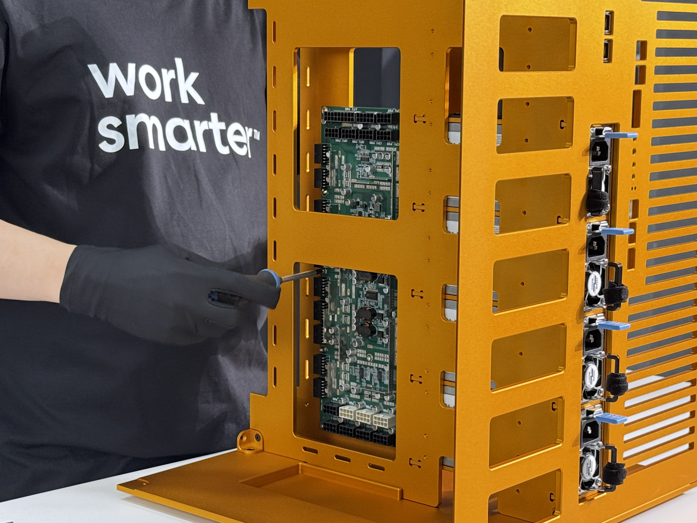
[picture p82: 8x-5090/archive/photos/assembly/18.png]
| 18 | Tighten all screws on the PSU board. |  |
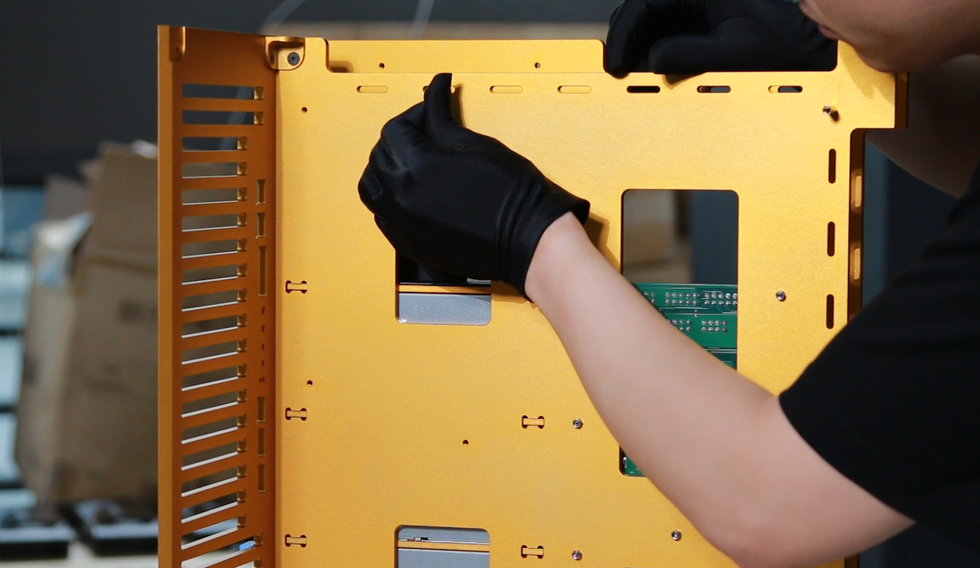
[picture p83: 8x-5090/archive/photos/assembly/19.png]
| 19 | Install M4 × 15 mm copper spacers into the M4 holes on the other side. |  |
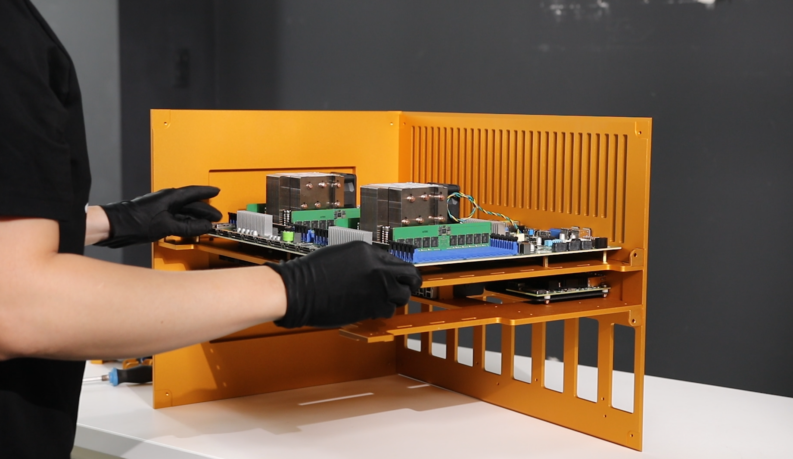
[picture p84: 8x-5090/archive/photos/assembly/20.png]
| 20 | Place the “Motherboard GENOA2D24G-2L+” into position. |  |
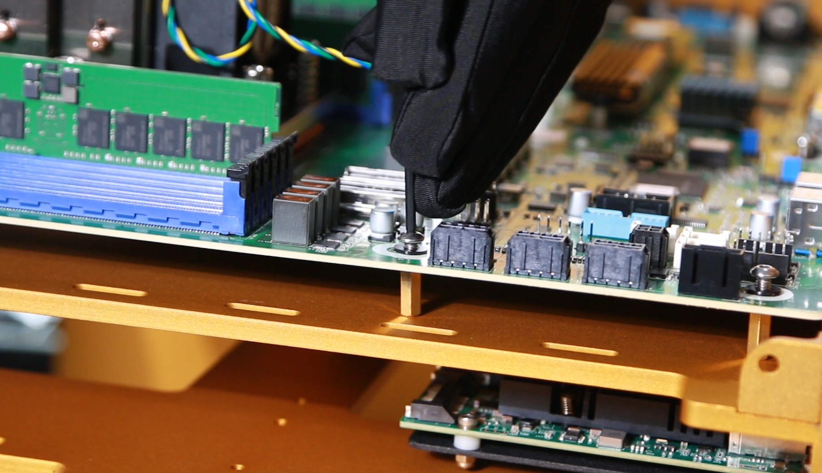
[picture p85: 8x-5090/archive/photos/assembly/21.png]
| 21 | Secure the motherboard to “Part 2 – CPU Plate” using M3 screws. |  |
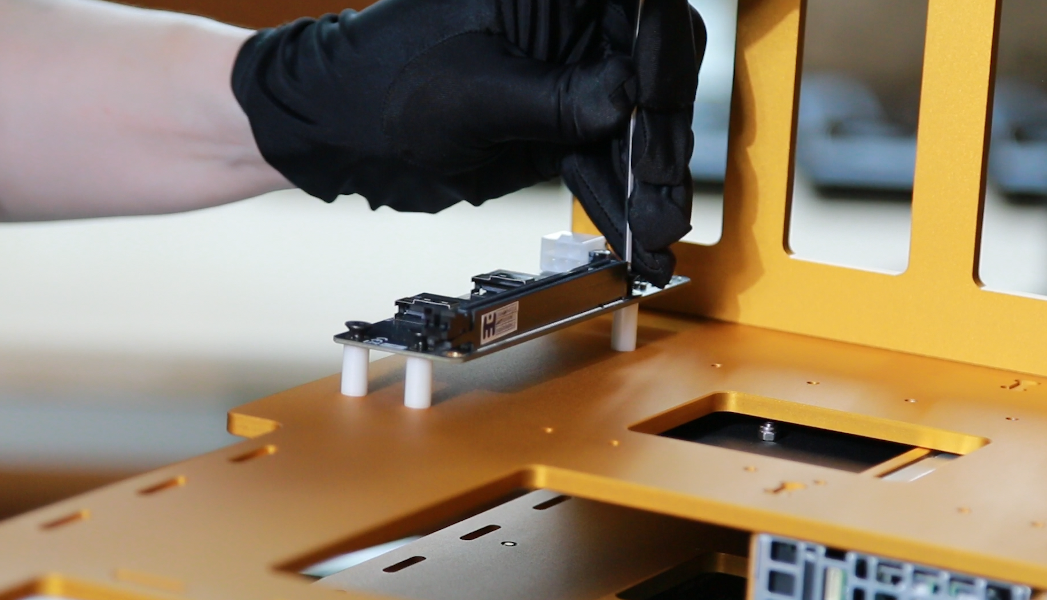
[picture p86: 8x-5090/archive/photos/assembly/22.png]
| 22 | Place 20 mm plastic spacers under the PCI board and secure them with M4 screws. |  |
| 23 | Install the remaining components. |  |
| 24 | The MCIO→PCIe x16 adapters seated on their standoffs — one per GPU slot. |  |
| 25 | The frame with all eight PCIe adapters installed, seen from the front. |  |
| 26 | Place the assembled parts upright. |  |
| 27 | Connect the PCI board cable to the motherboard. |  |
| 28 | Use zip ties to organize cables. |  |
| 29 | Connect the power cable to the motherboard. |  |
| 30 | Connect MCIO cable to MCIO adapter |  |
| 31 | Place “Part 6 – Top” into position and secure it with M4 screws and the support plate. |  |
| 32 | Install 8 GPUs. |  |
| 33 | Secure the GPUs to the support rail. |  |
| 34 | Organize the power supply cables. |  |
| 35 | Connect the power supply cables. |  |
| 36 | Connect the fan board cable, then place the fan board into position. |  |
| 37 | Secure “Part 7 – Side”. |  |
| 38 | Repeat for the other side. |  |
| 39 | Connect the main power supply. |  |

---

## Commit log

2026-08-05 8x-5090: rebuild as a 5U rack server; archive the CNC desktop case
    The 8x build moved from the CNC-milled desktop tower into a 5U rack
    chassis. Rewrite the guide around it:
    - assembly.md is now 13 steps, bare chassis to first boot, replacing the
    39-step CNC sequence
    - prepare-me.md is chassis-kit prep; the kit ships complete, so there is
    no milling, blasting, or anodizing
    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
    [Ethernet mount.step, Ethernet mount.stl, GPU mount.step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]
2026-08-05 4x-5090: new banner photo on the root README
    Replaces the hero shot in the 4x 5090 section with the wide bench photo
    of the four cards in the open cube frame. Encoded at q85 webp, 189 KB
    for 2560x1440.
2026-08-05 8x-5090: rack photos for steps 6-13; match the build-page format
    Ten more assembly photos wired into the guide — MCIO cables to the
    board, NVMe and the drive bay, the GPU mount panel, the 5090s and their
    12V-2x6 power, the fan cages, the PSU modules, and the finished machine.
    Converted from 27 MB of full-res shots to 1.6 MB of webp.
    Steps 7-11 gained the detail their photos show: the NVMe goes in with
    the drive bay, the GPU rails are laid out with the adapters, and the fan
    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
2026-08-13 8x-5090: assembly photos for steps 1-3
2026-08-17 2x-6000: new build — two RTX PRO 6000s in the 2x housing
2026-08-17 2x-6000: build photos, 720p build video, real board and CPU images
2026-08-17 2x-6000: fold the component checklist into the BOM; list the build on the root README
2026-08-21 4x-6000: rebuild the guide around the milled aluminium cube
    Drop the 5U rack chassis and its dual-socket EPYC platform. The build
    now runs on Intel Xeon W in the CNC-milled aluminium cube: new BOM,
    housing prep, and 23-step assembly from bare housing to closed box.
    Replace the rack photo set with this build's gallery, and move the
    section up next to the 4x 5090 on the root README.
